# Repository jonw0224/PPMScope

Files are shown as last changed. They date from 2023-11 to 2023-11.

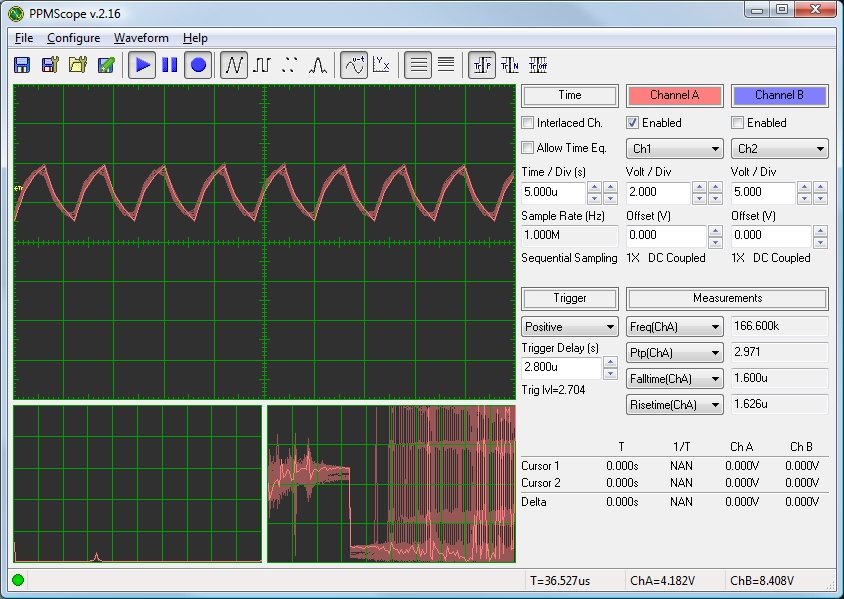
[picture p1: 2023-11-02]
Pictures/DSOScopeDebug20130410.jpg

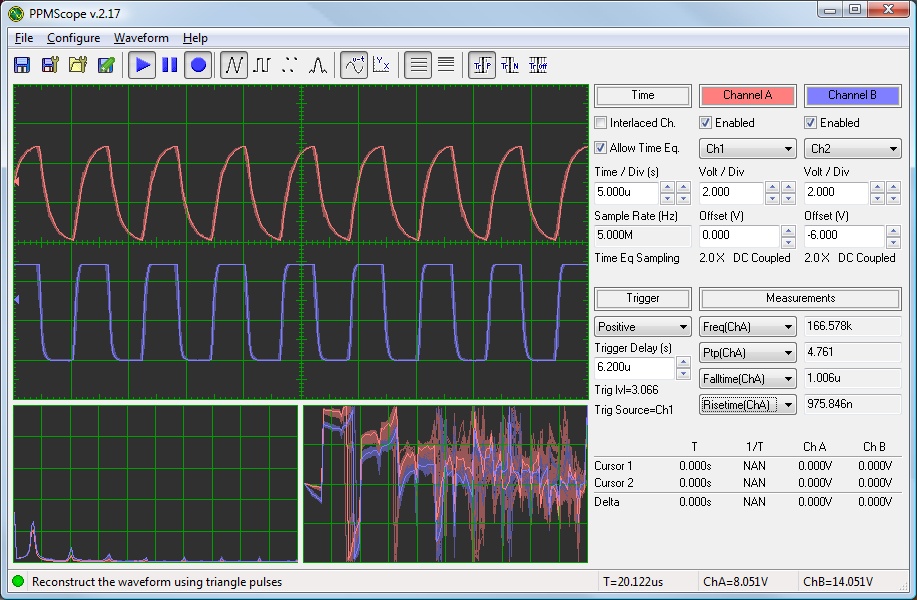
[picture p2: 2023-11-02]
Pictures/PPMScopeDebug20130410.jpg

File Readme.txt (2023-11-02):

PPMScope (PC-PIC-MaximADC Scope)
===============================================================================

Date:  4/17/2014
Author:  Jonathan Weaver, jonw0224@aim.com, http://jonw0224.tripod.com
Version:  2.19 for Windows
Copyright (C) 2014 Jonathan Weaver

PPMScope is a do-it-yourself oscilloscope with an open source design.  The
intent is that the project can be constructed by an electronics hobbiest using
the instructions included.  The design is a compromise between features and
cost.  The bandwidth is lower than a commercial scope, so it's use is limited
to signals of 500 kHz and below.  It's sample buffer is also smaller than
a commercial scope, however sufficient for most oscilloscope functions.

This is a version based on the PIC16F877A microcontroller running with a 20MHz 
clock.  The maximum sampling rate is 1 MHz with a 5 Mhz equivalent sampling
mode.  Currently, the only computer interface supported is the serial port 
and the parallel port.  I have plans to support USB in the future.

Good luck on the construction and I hope you enjoy your oscilloscope.  I am
happy to answer any questions or provide technical support for this design.

See help file, ppmscope.chm, for details on the construction, calibration, 
operation, and software use for the oscilloscope.

Installation of INPOUT to communicate with the parallel port
===============================================================================

This software uses third party software to communicate to the parallel port.  
Inpout is a DLL written originally by Logix4U.net and later adapted for use on
Windows 7 and 64 bit versions of XP and Vista by Phillip Gibbons 
(Phil@highrez.co.uk).  It can be downloaded at 
http://www.highrez.co.uk/downloads/inpout32/

I have included the software in the folder InpOutBinaries_1500

To install the parallel port driver under Windows 7 or Vista, either 

(1) Run PPMScope.exe with administrator privilages the first time it is used, 
    to allow PPMScope to automatically install the driver, or

(2) Run the executable InstallDriver.exe

FOLDER CONTENTS:
===============================================================================

Datasheets -
The manufacturer Datasheets for integrated circuits used.

PCsource -
The source files for the PC, written in C and compiled using dev-cpp v.4.9.9.2
(www.bloodshed.net) or Code::Blocks (www.codeblocks.org).

PICasm -
The PIC assembly source files.

PIChex -
The compiled hex file for the PIC16F877 or PIC16F877A microcontroller.  The 
file was compiled using MPLAB IDE v.8.85 (www.microchip.com).

Schematics -
The schematics for the Oscilloscope in PDF format and TINYCAD 
(tinycad.sourceforge.net) format.

PCB -
The printed circuit board layouts in PDF format and FreePCB 
(www.freepcb.com) format.

Spice - 
LTSpiceIV (http://www.linear.com/designtools/software/#LTspice) model for the
analog portions of the circuit.

REVISION HISTORY:
===============================================================================

Version 2.19 for Windows
-------------------------------------------------------------------------------

See help file for details on the software.

LICENSE AND COPYRIGHT NOTICE FOR SOFTWARE AND FIRMWARE:
===============================================================================

Copyright (C) 2014 Jonathan Weaver

This program is free software: you can redistribute it and/or modify
it under the terms of the GNU General Public License as published by
the Free Software Foundation, either version 3 of the License, or
(at your option) any later version.

This program is distributed in the hope that it will be useful,
but WITHOUT ANY WARRANTY; without even the implied warranty of
MERCHANTABILITY or FITNESS FOR A PARTICULAR PURPOSE.  See the
GNU General Public License for more details.

You should have received a copy of the GNU General Public License
along with this program.  If not, see <http://www.gnu.org/licenses/>.

HARDWARE DESIGN LICENSE:
===============================================================================

Copyright (C) 2014 Jonathan Weaver

The hardware design is licensed under the (cc) Creative Commons 
Attribution-ShareAlike 3.0 Unported (CC BY-SA 3.0) license.  

You are free:

 to Share — to copy, distribute and transmit the work 
 
 to Remix — to adapt the work 

 to make commercial use of the work 

Under the following conditions:

 Attribution — You must attribute the work in the manner specified by the 
   author or licensor (but not in any way that suggests that they endorse 
   you or your use of the work). 

 Share Alike — If you alter, transform, or build upon this work, you may 
   distribute the resulting work only under the same or similar license to this
   one. 

With the understanding that: 

 Waiver— Any of the above conditions can be waived if you get permission from 
   the copyright holder. 

 Public Domain— Where the work or any of its elements is in the public domain 
   under applicable law, that status is in no way affected by the license. 

Other Rights— In no way are any of the following rights affected by the 
license:

 * Your fair dealing or fair use rights, or other applicable copyright 
   exceptions and limitations; 

 * The author's moral rights; 

 * Rights other persons may have either in the work itself or in how the work 
   is used, such as publicity or privacy rights. 

See the Creative Commons License for more details (cc-by-sa-30.txt or 
http://creativecommons.org/licenses/by-sa/3.0/).

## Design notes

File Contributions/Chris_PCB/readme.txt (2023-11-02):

PCB Layout for PPMScope 1.20 by Krzysztof Passowicz

This layout is optimized for single sided board etching.

Contents
========

(1) 28PPMScope v1_2.fpc - FreePCB layout (FreePCB can be downloaded at www.freepcb.com)
(2) bottom_copper.pdf - PDF of bottom side of the layout
(3) bottom_copper.png - Image of bottom side of the layout
(4) bottom_copper.grb - Gerber of bottom side of the layout

License
=======

Copyright (c) 2012 Krzysztof Passowicz

Images and files are licensed under the Creative Commons Attribution-ShareAlike 3.0 Unported license.  For the full license terms, see cc-by-sa.txt.

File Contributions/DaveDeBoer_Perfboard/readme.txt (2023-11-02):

Prototyping perfboard layout for PPMScope v.1.05 contributed by Dave de Boer

Contents
========

(1) scope_v1.05.rst - Lochmaster design file (Lochmaster can be downloaded from www.abacom-online.de).
(2) PPMScope_1.05_top.jpg - Component side layout image
(3) PPMScope_1.05_bot.jpg - Solder side layout image
(4) Build_DavidDeBoer_top.jpg - Component side image of Dave's build
(5) Build_DavidDeBoer_bot.jpg - Solder side image of Dave's build
(6) Build_DavidDeBoer_complete.jpg - Image of the entire scope assembled

License
=======

Copyright (c) 2012 Dave de Boer

Images and files are licensed under the Creative Commons Attribution-ShareAlike 3.0 Unported license.  For the full license terms, see cc-by-sa.txt.

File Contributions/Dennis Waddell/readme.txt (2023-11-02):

PCB Layout and Schematics for Eagle for PPMScope 1.20 by Dennis Waddell.

The files can be used with the free version of Eagle, which can be downloaded at:

http://www.cadsoftusa.com/download-eagle/

License
=======

Copyright (c) 2012 Dennis Waddell

Images and files are licensed under the Creative Commons Attribution-ShareAlike 3.0 Unported license.  For the full license terms, see cc-by-sa.txt.

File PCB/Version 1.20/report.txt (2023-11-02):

FreePCB project report (default units = MIL)
============================================
Project name: PPMScope
Project file: E:\Projects\PPMScope\PCB\Version 1.20\PPMScope v1_2.fpc
Default library folder: c:\program files\freepcb\lib

Drill list
==========
NUMBER  DIAMETER
------  --------
   60   40 MIL
  323   35 MIL
    4   125 MIL

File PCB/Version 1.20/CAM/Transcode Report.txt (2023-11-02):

   ---- Transcoding 'C:\jww\Projects\PPMScope\PCB\Version 1.20\CAM\top_copper.grb' ----   Thu Apr 17 14:20:18 2014

D11   --> D100
D12   --> D101
-----------------------------------------------------------------

   ---- Transcoding 'C:\jww\Projects\PPMScope\PCB\Version 1.20\CAM\top_copper.grb' ----   Thu Apr 17 14:24:19 2014

D18   --> D100
D19   --> D101
D20   --> D102
-----------------------------------------------------------------

   ---- Transcoding 'C:\jww\Projects\PPMScope\PCB\Version 1.20\CAM\top_silk.grb' ----   Thu Apr 17 14:24:19 2014

D11   --> D103
D12   --> D104
-----------------------------------------------------------------

   ---- Transcoding 'C:\jww\Projects\PPMScope\PCB\Version 1.20\CAM\top_copper.grb' ----   Thu Apr 17 14:27:24 2014

D18   --> D100
D19   --> D101
D20   --> D102
-----------------------------------------------------------------

   ---- Transcoding 'C:\jww\Projects\PPMScope\PCB\Version 1.20\CAM\top_silk.grb' ----   Thu Apr 17 14:27:24 2014

D11   --> D103
D12   --> D104
-----------------------------------------------------------------

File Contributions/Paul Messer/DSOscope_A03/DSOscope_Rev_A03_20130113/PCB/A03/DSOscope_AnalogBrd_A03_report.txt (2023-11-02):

FreePCB project report (default units = MIL)
============================================
Project name: DSOscope_AnalogBrd
Project file: C:\Users\pmesser\_Paul\Design\DSOscope\PCB\A03\DSOscope_AnalogBrd_A03.fpc
Default library folder: c:\users\pmesser\_paul\design\my_freepcb_library

Board statistics
==============
Number of copper layers: 4
Number of board outlines: 1
Board outline(s) extent: X = 3700 MIL; Y = 1900 MIL
Number of parts: 81
Number of pins: 246 (88 through-hole, 158 SMT)
Number of vias: 75
Number of holes: 163

Drill list
==========
NUMBER  DIAMETER
------  --------
   75   21 MIL
    3   55 MIL
    2   100 MIL
   63   40 MIL
   16   35 MIL
    4   43 MIL

Part list
=========
For parts on top: the angle is in degrees CCW, as viewed from the top
For parts on the bottom: the angle is in degrees CCW, as viewed from the bottom by flipping the PCB left-right
All centroid coordinates are as viewed from the top

REF          PACKAGE  VALUE        FOOTPRINT  PINS  HOLES    SIDE  ANGLE  CENT X  CENT Y  PIN1 X  PIN1 Y  GLUE W  GLUE X  GLUE Y
---          -------  -----        ---------  ----  -----    ----  -----  ------  ------  ------  ------  ------  ------  ------
 C1             1206                    1206     2      0     top    180   337.5     490     270     490      10   337.5   557.5
C10             0805                    0805     2      0     top     90    1660    1165    1660    1120      10    1615    1165
C11             0805                    0805     2      0     top     90    2620    1025    2620     980      10    2575    1025
C12             0805                    0805     2      0     top    180    2285     800    2240     800      10    2285     845
C13             0805                    0805     2      0     top      0    1295     550    1340     550      10    1295     505
C14             0603                    0603     2      0     top     90    1000  1243.5    1000    1210      10   966.5  1243.5
C15             0603                    0603     2      0     top     90    2700  1283.5    2700    1250      10  2666.5  1283.5
C16             0805                    0805     2      0  bottom    270     940     745     940     790      10     895     745
C17             0805                    0805     2      0     top      0    1155     360    1200     360      10    1155     315
C18             0805                    0805     2      0  bottom    180    2375     700    2330     700      10    2375     655
 C2             0805                    0805     2      0     top     90     500     535     500     490      10     455     535
 C3             1206                    1206     2      0     top      0  3312.5     550    3380     550      10  3312.5   482.5
 C4             0805                    0805     2      0     top    270    3150     505    3150     550      10    3195     505
 C5             0805                    0805     2      0     top     90     950    1455     950    1410      10     905    1455
 C6             0805                    0805     2      0     top     90    1330    1585    1330    1540      10    1285    1585
 C7             0805                    0805     2      0     top    270    2380    1385    2380    1430      10    2425    1385
 C8             0805                    0805     2      0     top    180    2605     340    2560     340      10    2605     385
 C9             0805                    0805     2      0     top     90    1230    1005    1230     960      10    1185    1005
 D1           SOD323                  SOD323     2      0     top    270     910     685     910     760      25     910     685
D10           SOD123                  SOD123     2      0     top      0  2752.5     420    2840     420      25  2752.5     420
D11       LED175VERT              LED175VERT     2      2     top    180     250    1040     200    1040
 D2           SOD323                  SOD323     2      0     top     90     840     685     840     610      25     840     685
 D3            SOT23                   SOT23     3      0     top      0    1900     318    1940     280      10    1902     318
 D4           SOD123                  SOD123     2      0     top    180   847.5     520     760     520      25   847.5     520
 D5           SOD123                  SOD123     2      0     top    180   847.5     430     760     430      25   847.5     430
 D6           SOD323                  SOD323     2      0     top      0    2745     660    2820     660      25    2745     660
 D7           SOD323                  SOD323     2      0     top    180    2745     590    2670     590      25    2745     590
 D8            SOT23                   SOT23     3      0     top      0    2140     318    2180     280      10    2142     318
 D9           SOD123                  SOD123     2      0     top      0  2752.5     510    2840     510      25  2752.5     510
 J1           TBLKx2                  TBLKx2     2      2  bottom     90     150     550     150     550
 J2           TBLKx2                  TBLKx2     2      2  bottom    270    3550     750    3550     750
 J3  SqPinSocket1x18         SqPinSocket1x18    18     18  bottom    180    1000     150    1000     150
 J4   SqPinSocket1x7          SqPinSocket1x7     7      7  bottom     90    3550    1150    3550    1150
 R1             0805                    0805     2      0     top     90     580     505     580     460      10     535     505
R10             0805                    0805     2      0     top      0     555    1050     600    1050      10     555    1005
R11             0805                    0805     2      0     top      0     915    1580     960    1580      10     915    1535
R12             0805                    0805     2      0     top     90     870    1455     870    1410      10     825    1455
R13            PV36W                   PV36W     3      3     top    270     180    1590     180    1590
R14             0805                    0805     2      0     top    270    3060     505    3060     550      10    3105     505
R15             0805                    0805     2      0     top     90    2970     505    2970     460      10    2925     505
R16             0805                    0805     2      0     top     90    2870     795    2870     750      10    2825     795
R17             0805                    0805     2      0     top      0    1485    1580    1530    1580      10    1485    1535
R18             0805                    0805     2      0     top     90    2770    1255    2770    1210      10    2725    1255
R19             0805                    0805     2      0     top    270    2790     795    2790     840      10    2835     795
 R2             0805                    0805     2      0     top     90     360     655     360     610      10     315     655
R20             0805                    0805     2      0     top      0    2475    1580    2520    1580      10    2475    1535
R21             0805                    0805     2      0     top     90    2850    1255    2850    1210      10    2805    1255
R22             0805                    0805     2      0     top      0    1875    1100    1920    1100      10    1875    1055
R23             0805                    0805     2      0     top    180    3145    1050    3100    1050      10    3145    1095
R24             0805                    0805     2      0     top    180    2785    1580    2740    1580      10    2785    1625
R25             0805                    0805     2      0     top     90    2830    1445    2830    1400      10    2785    1445
R26             0805                    0805     2      0     top    270    2570     585    2570     630      10    2615     585
R27             0805                    0805     2      0     top    180    2335     340    2290     340      10    2335     385
R28             0805                    0805     2      0     top    270    2430     855    2430     900      10    2475     855
R29         POTVERT1                POTVERT1     5      5     top    180    1850     700    1460     550
 R3             0805                    0805     2      0     top     90     360     825     360     780      10     315     825
R30             0805                    0805     2      0     top    180     195    1220     150    1220      10     195    1265
R31            PV36W                   PV36W     3      3     top    270    3400    1590    3400    1590
R32             0805                    0805     2      0     top     90    1650    1615    1650    1570      10    1605    1615
R33             0805                    0805     2      0     top     90     280     825     280     780      10     235     825
R34             0805                    0805     2      0  bottom     90    2830     745    2830     700      10    2875     745
R35             0805                    0805     2      0  bottom     90     690     535     690     490      10     735     535
R36             0805                    0805     2      0  bottom    270    3320     745    3320     790      10    3275     745
R37             0805                    0805     2      0     top    270    2070    1445    2070    1490      10    2115    1445
 R4             0805                    0805     2      0     top    270    1330    1255    1330    1300      10    1375    1255
 R5             0805                    0805     2      0     top     90     930    1255     930    1210      10     885    1255
 R6             0805                    0805     2      0     top     90     400     995     400     950      10     355     995
 R7             0805                    0805     2      0     top    180    1175    1580    1130    1580      10    1175    1625
 R8             0805                    0805     2      0     top     90     850    1255     850    1210      10     805    1255
 R9             0805                    0805     2      0     top     90    1330    1075    1330    1030      10    1285    1075
SW1       SWDP3TSLD2              SWDP3TSLD2     8      8     top    180     250     250     250     250
SW2     SWDPDTTOGSM1            SWDPDTTOGSM1     6      6     top     90     605     800     690     700
SW3     SWDPDTTOGSM1            SWDPDTTOGSM1     6      6     top     90     605    1400     690    1300
SW4     SWDPDTTOGSM1            SWDPDTTOGSM1     6      6     top      0    1850    1405    1950    1490
SW5       SWDP3TSLD2              SWDP3TSLD2     8      8     top    180    3050     250    3050     250
SW6     SWDPDTTOGSM1            SWDPDTTOGSM1     6      6     top     90    3095     800    3180     700
SW7     SWDPDTTOGSM1            SWDPDTTOGSM1     6      6     top     90    3095    1400    3180    1300
 U1            SOIC8                   SOIC8     8      0     top    180    1155    1320    1080    1210      10    1155    1285
 U2            SOIC8                   SOIC8     8      0     top    180    2545    1320    2470    1210      10    2545    1285
 U3            SOIC8                   SOIC8     8      0     top    180    1505    1320    1430    1210      10    1505    1285
 U4            SOIC8                   SOIC8     8      0     top      0    2405     580    2480     690      10    2405     615

Gerber file settings
====================
Include board outline: YES
Include moires: NO
Include layer description text: NO
Include pilot holes: YES
Connect SMT pins to copper areas: YES
Use thermals for SMT pins: YES
Use thermals for through-hole pins: YES
Use thermals for vias: YES
Make solder-mask cutouts for vias: NO
Use 90-degree thermals for round pins: NO
Copper to copper-fill clearance: 15 MIL
Hole-edge to copper-fill clearance: 15 MIL
Solder mask clearance: 8 MIL
Pilot hole diameter: 10 MIL
Minimum silkscreen line width: 7 MIL
Thermal relief line width: 25 MIL
Board outline line width: 10 MIL
Minimum annular ring width (pins): 7 MIL
Minimum annular ring width (vias): 5 MIL
Amount to shrink SMT pads for paste mask: 0 MIL

DRC settings
============
Minimum trace width: 10 MIL
Minimum pad to pad clearance: 10 MIL
Minimum pad to trace clearance: 10 MIL
Minimum trace to trace clearance: 10 MIL
Minimum hole to copper clearance: 15 MIL
Minimum hole to hole clearance: 25 MIL
Minimum annular ring (pins): 7 MIL
Minimum annular ring (vias): 5 MIL
Minimum board edge to copper clearance: 25 MIL
Minimum board edge to hole clearance: 25 MIL
Minimum copper area to copper area clearance: 10 MIL

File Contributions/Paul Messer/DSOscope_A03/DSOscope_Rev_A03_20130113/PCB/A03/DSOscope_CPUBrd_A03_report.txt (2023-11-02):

FreePCB project report (default units = MIL)
============================================
Project name: DSOscope_CPUBrd
Project file: C:\Users\pmesser\_Paul\Design\DSOscope\PCB\A03\DSOscope_CPUBrd_A03.fpc
Default library folder: c:\users\pmesser\_paul\design\my_freepcb_library

Board statistics
==============
Number of copper layers: 4
Number of board outlines: 3
Board outline(s) extent: X = 3700 MIL; Y = 1900 MIL
Number of parts: 91 (without footprints = 14)
Number of pins: 264 (57 through-hole, 207 SMT)
Number of vias: 96
Number of holes: 153

Drill list
==========
NUMBER  DIAMETER
------  --------
   96   21 MIL
   10   35 MIL
    2   90 MIL
   37   41 MIL
    4   36 MIL
    4   52 MIL

Part list
=========
For parts on top: the angle is in degrees CCW, as viewed from the top
For parts on the bottom: the angle is in degrees CCW, as viewed from the bottom by flipping the PCB left-right
All centroid coordinates are as viewed from the top

   REF    PACKAGE  VALUE  FOOTPRINT  PINS  HOLES    SIDE  ANGLE  CENT X  CENT Y  PIN1 X  PIN1 Y  GLUE W  GLUE X  GLUE Y
   ---    -------  -----  ---------  ----  -----    ----  -----  ------  ------  ------  ------  ------  ------  ------
 BOM_1  NOPACKAGE                                                                              
BOM_10  NOPACKAGE                                                                              
BOM_11  NOPACKAGE                                                                              
BOM_12  NOPACKAGE                                                                              
BOM_13  NOPACKAGE                                                                              
BOM_14  NOPACKAGE                                                                              
 BOM_2  NOPACKAGE                                                                              
 BOM_3  NOPACKAGE                                                                              
 BOM_4  NOPACKAGE                                                                              
 BOM_5  NOPACKAGE                                                                              
 BOM_6  NOPACKAGE                                                                              
 BOM_7  NOPACKAGE                                                                              
 BOM_8  NOPACKAGE                                                                              
 BOM_9  NOPACKAGE                                                                              
    C1       0805              0805     2      0  bottom    180    1405     750    1360     750      10    1405     705
   C10     RAD248            RAD248     2      2     top      0    2420     400    2470     400
   C11       0805              0805     2      0  bottom      0    2955    1590    3000    1590      10    2955    1635
   C12     RAD248            RAD248     2      2     top     90    2790    1750    2790    1700
   C13     RAD394            RAD394     2      2     top    270    3500    1110    3500    1210
   C14       0805              0805     2      0  bottom    270    3400    1105    3400    1150      10    3355    1105
   C15       0805              0805     2      0     top     90    2710     555    2710     510      10    2665     555
   C16     RAD248            RAD248     2      2     top     90    2710    1220    2710    1170
   C17       0805              0805     2      0     top     90    3230    1265    3230    1220      10    3185    1265
   C18     RAD394            RAD394     2      2     top     90    3500     700    3500     600
   C19       0805              0805     2      0  bottom     90    3400     915    3400     870      10    3445     915
    C2       0805              0805     2      0  bottom     90     770     915     770     870      10     815     915
   C20       0805              0805     2      0  bottom    270    3000     785    3000     830      10    2955     785
   C21       0603              0603     2      0  bottom     90    2200   773.5    2200     740      10  2233.5   773.5
   C22       0805              0805     2      0  bottom     90    1870     875    1870     830      10    1915     875
   C23       0603              0603     2      0  bottom      0  1796.5     660    1830     660      10  1796.5   693.5
   C24       0805              0805     2      0     top     90    2610     355    2610     310      10    2565     355
   C25       0805              0805     2      0  bottom    180    2815     660    2770     660      10    2815     615
    C3       0603              0603     2      0     top      0   506.5     840     540     840      10   506.5   806.5
    C4       0603              0603     2      0     top    180   313.5     840     280     840      10   313.5   873.5
    C5       0805              0805     2      0  bottom    270     980     955     980    1000      10     935     955
    C6       0805              0805     2      0  bottom     90     770    1085     770    1040      10     815    1085
    C7       0805              0805     2      0     top    180     615    1560     570    1560      10     615    1605
    C8     RAD248            RAD248     2      2     top     90    2490    1080    2490    1030
    C9       0805              0805     2      0     top     90    2710     745    2710     700      10    2665     745
    D1    DO35SMT           DO35SMT     2      0     top    180     390    1670     290    1670      10     390    1770
    D2     SOD123            SOD123     2      0     top    180   677.5    1670     590    1670      25   677.5    1670
    D4       DO41              DO41     2      2     top     90    3600    1550    3600    1300
    D5       DO41              DO41     2      2     top     90    3250     850    3250     600
    F1    miniSMD           miniSMD     2      0     top    180    2210    1130    2110    1130      10    2210    1230
    J1  CutStrap1         CutStrap1     3      2     top     90     300     980     300     980
    J2   SqPin1x7          SqPin1x7     7      7     top     90     150    1150     150    1150
    J3  SqPin1x18         SqPin1x18    18     18  bottom      0    2700     150    2700     150
    J4   SqPin1x6          SqPin1x6     6      6     top     90    1390    1290    1390    1290
    J5      USBB1             USBB1     6      6     top      0    1850    1685    1801    1410
    L1    INDUCT1           INDUCT1     2      0     top    180    3340    1670    3340    1550      25    3340    1670
    L2    INDUCT1           INDUCT1     2      0     top     90    2980     750    3100     750      25    2980     750
    L3       1210              1210     2      0     top    270    2720   352.5    2720     420      10  2787.5   352.5
    L4       1210              1210     2      0  bottom    270    2830   822.5    2830     890      10  2762.5   822.5
    R1       0805              0805     2      0     top     90     520    1205     520    1160      10     475    1205
   R10       0805              0805     2      0     top    180     785    1560     740    1560      10     785    1605
   R11       0805              0805     2      0     top    180     445    1560     400    1560      10     445    1605
   R12       0805              0805     2      0  bottom    270     520    1205     520    1250      10     475    1205
   R13       0805              0805     2      0     top    180     445    1480     400    1480      10     445    1525
   R14       0805              0805     2      0     top      0     685    1350     730    1350      10     685    1305
   R15       0805              0805     2      0     top     90    1860     545    1860     500      10    1815     545
   R16       0805              0805     2      0     top     90    2000     545    2000     500      10    1955     545
   R17       0805              0805     2      0     top    180    1215    1690    1170    1690      10    1215    1735
   R18       0805              0805     2      0     top    180    1215    1790    1170    1790      10    1215    1835
    R2       0805              0805     2      0     top    270    1000     365    1000     410      10    1045     365
   R21       0805              0805     2      0     top    270    2920    1435    2920    1480      10    2965    1435
   R22       0805              0805     2      0     top    270    3000    1435    3000    1480      10    3045    1435
   R23       0805              0805     2      0     top     90    3100    1435    3100    1390      10    3055    1435
   R24       0805              0805     2      0     top    270    2760    1535    2760    1580      10    2805    1535
   R25       0805              0805     2      0     top    270    2840    1535    2840    1580      10    2885    1535
   R26       0805              0805     2      0     top      0    2795    1410    2840    1410      10    2795    1365
   R27       0805              0805     2      0     top    180    2715    1040    2670    1040      10    2715    1085
   R28       0805              0805     2      0     top    180    2715     960    2670     960      10    2715    1005
   R29       0805              0805     2      0     top      0    2925    1310    2970    1310      10    2925    1265
    R3       0805              0805     2      0     top      0     725     720     770     720      10     725     675
   R30       0805              0805     2      0     top    180    2925    1220    2880    1220      10    2925    1265
   R31       0805              0805     2      0     top    180    3095    1310    3050    1310      10    3095    1355
   R32       0805              0805     2      0     top     90    1760    1155    1760    1110      10    1715    1155
   R33       0805              0805     2      0  bottom     90     850    1315     850    1270      10     895    1315
   R34       0805              0805     2      0  bottom     90     930    1315     930    1270      10     975    1315
   R35       0805              0805     2      0     top      0     685    1430     730    1430      10     685    1385
    R4       0805              0805     2      0     top      0    2245     810    2290     810      10    2245     765
    R5       0805              0805     2      0     top      0    1205    1550    1250    1550      10    1205    1505
    R6       0805              0805     2      0     top    180    1635    1200    1590    1200      10    1635    1245
    R7       0805              0805     2      0     top      0    1675    1280    1720    1280      10    1675    1235
    R8       0805              0805     2      0     top    270     910    1605     910    1650      10     955    1605
    R9       0805              0805     2      0     top    270     990    1605     990    1650      10    1035    1605
    U1     SSOP28            SSOP28    28      0     top    180    1489   577.5    1320     410      25    1489   577.5
    U2     TQFP44            TQFP44    44      0     top     90  1002.5  1037.5  1272.5     880      10  1002.5  1037.5
    U4      SOIC8             SOIC8     8      0     top      0    3025    1690    3100    1800      10    3025    1725
    U5      SOIC8             SOIC8     8      0     top     90    3000    1055    3110     980      10    3035    1055
    X1   HC49VERT          HC49VERT     2      2     top     90     375     680     470     680

Gerber file settings
====================
Include board outline: YES
Include moires: NO
Include layer description text: NO
Include pilot holes: YES
Connect SMT pins to copper areas: NO
Use thermals for SMT pins: YES
Use thermals for through-hole pins: YES
Use thermals for vias: YES
Make solder-mask cutouts for vias: NO
Use 90-degree thermals for round pins: NO
Copper to copper-fill clearance: 15 MIL
Hole-edge to copper-fill clearance: 15 MIL
Solder mask clearance: 8 MIL
Pilot hole diameter: 10 MIL
Minimum silkscreen line width: 5 MIL
Thermal relief line width: 20 MIL
Board outline line width: 5 MIL
Minimum annular ring width (pins): 7 MIL
Minimum annular ring width (vias): 5 MIL
Amount to shrink SMT pads for paste mask: 0 MIL

DRC settings
============
Minimum trace width: 10 MIL
Minimum pad to pad clearance: 10 MIL
Minimum pad to trace clearance: 10 MIL
Minimum trace to trace clearance: 10 MIL
Minimum hole to copper clearance: 15 MIL
Minimum hole to hole clearance: 25 MIL
Minimum annular ring (pins): 7 MIL
Minimum annular ring (vias): 5 MIL
Minimum board edge to copper clearance: 25 MIL
Minimum board edge to hole clearance: 25 MIL
Minimum copper area to copper area clearance: 10 MIL

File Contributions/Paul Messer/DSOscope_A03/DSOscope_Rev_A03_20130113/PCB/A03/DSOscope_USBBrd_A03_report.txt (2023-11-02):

FreePCB project report (default units = MIL)
============================================
Project name: DSOscope_USBBrd_A03
Project file: C:\Users\pmesser\_Paul\Design\DSOscope\PCB\A03\DSOscope_USBBrd_A03.fpc
Default library folder: c:\users\pmesser\_paul\design\my_freepcb_library

Board statistics
==============
Number of copper layers: 4
Number of board outlines: 1
Board outline(s) extent: X = 1150 MIL; Y = 925 MIL
Number of parts: 18
Number of pins: 66 (6 through-hole, 60 SMT)
Number of vias: 19
Number of holes: 25

Drill list
==========
NUMBER  DIAMETER
------  --------
   19   21 MIL
    6   41 MIL

Part list
=========
For parts on top: the angle is in degrees CCW, as viewed from the top
For parts on the bottom: the angle is in degrees CCW, as viewed from the bottom by flipping the PCB left-right
All centroid coordinates are as viewed from the top

REF         PACKAGE  VALUE       FOOTPRINT  PINS  HOLES    SIDE  ANGLE  CENT X  CENT Y  PIN1 X  PIN1 Y  GLUE W  GLUE X  GLUE Y
---         -------  -----       ---------  ----  -----    ----  -----  ------  ------  ------  ------  ------  ------  ------
 C1            0805                   0805     2      0     top    180     815     535     770     535      10     815     580
 C2            0805                   0805     2      0     top    270      80     420      80     465      10     125     420
 C3            0805                   0805     2      0  bottom      0     385     575     430     575      10     385     620
 D1       1206DIODE              1206DIODE     2      0     top      0   182.5     825     250     825      10   182.5   757.5
 D2       1206DIODE              1206DIODE     2      0     top    180   457.5     825     390     825      10   457.5   892.5
 L1            0805                   0805     2      0     top    180     815     455     770     455      10     815     500
 P1  SqPinSocket1x6         SqPinSocket1x6     6      6  bottom     90    1000     325    1000     325
 R1            0805                   0805     2      0     top     90     100     650     100     605      10      55     650
R10            0805                   0805     2      0  bottom      0     165      85     210      85      10     165     130
 R2            0805                   0805     2      0     top      0     705     825     750     825      10     705     780
 R3            0805                   0805     2      0     top      0     735     245     780     245      10     735     200
 R4            0805                   0805     2      0     top      0     735     165     780     165      10     735     120
 R5            0805                   0805     2      0     top      0     555      85     600      85      10     555      40
 R6            0805                   0805     2      0     top    180     175      85     130      85      10     175     130
 R7            0805                   0805     2      0  bottom    180     745     245     700     245      10     745     200
 R8            0805                   0805     2      0  bottom    180     745     165     700     165      10     745     120
 R9            0805                   0805     2      0  bottom    180     565      85     520      85      10     565      40
 U1          SSOP28                 SSOP28    28      0     top    180     369   422.5     200     255      25     369   422.5

Gerber file settings
====================
Include board outline: YES
Include moires: NO
Include layer description text: NO
Include pilot holes: YES
Connect SMT pins to copper areas: NO
Use thermals for SMT pins: YES
Use thermals for through-hole pins: YES
Use thermals for vias: YES
Make solder-mask cutouts for vias: NO
Use 90-degree thermals for round pins: NO
Copper to copper-fill clearance: 15 MIL
Hole-edge to copper-fill clearance: 15 MIL
Solder mask clearance: 8 MIL
Pilot hole diameter: 10 MIL
Minimum silkscreen line width: 5 MIL
Thermal relief line width: 20 MIL
Board outline line width: 5 MIL
Minimum annular ring width (pins): 7 MIL
Minimum annular ring width (vias): 5 MIL
Amount to shrink SMT pads for paste mask: 0 MIL

DRC settings
============
Minimum trace width: 10 MIL
Minimum pad to pad clearance: 10 MIL
Minimum pad to trace clearance: 10 MIL
Minimum trace to trace clearance: 10 MIL
Minimum hole to copper clearance: 15 MIL
Minimum hole to hole clearance: 25 MIL
Minimum annular ring (pins): 7 MIL
Minimum annular ring (vias): 5 MIL
Minimum board edge to copper clearance: 25 MIL
Minimum board edge to hole clearance: 25 MIL
Minimum copper area to copper area clearance: 10 MIL

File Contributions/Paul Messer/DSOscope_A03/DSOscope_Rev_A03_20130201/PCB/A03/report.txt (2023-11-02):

FreePCB project report (default units = MIL)
============================================
Project name: DSOscope_AnalogBrd
Project file: C:\Google Drive\Projects\PPMScope\Contributions\Paul Messer\DSOscope_A03\DSOscope_Rev_A03_20130201\PCB\A03\DSOscope_AnalogBrd_A03.fpc
Default library folder: c:\users\pmesser\_paul\design\my_freepcb_library

Drill list
==========
NUMBER  DIAMETER
------  --------
   20   21 MIL
    3   55 MIL
    2   100 MIL
   63   40 MIL
    2   14 MIL
   16   35 MIL
    4   43 MIL
   52   30 MIL

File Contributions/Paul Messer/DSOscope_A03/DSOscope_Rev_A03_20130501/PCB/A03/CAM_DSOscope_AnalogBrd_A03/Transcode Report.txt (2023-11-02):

   ---- Transcoding 'C:\jww\Projects\PPMScope\Contributions\Paul Messer\DSOscope_A03\DSOscope_Rev_A03_20130501\PCB\A03\CAM_DSOscope_AnalogBrd_A03\bottom_silk.grb' ----   Fri Aug 15 15:07:52 2014

D11   --> D100
-----------------------------------------------------------------

   ---- Transcoding 'C:\jww\Projects\PPMScope\Contributions\Paul Messer\DSOscope_A03\DSOscope_Rev_A03_20130501\PCB\A03\CAM_DSOscope_AnalogBrd_A03\inner_copper_1.grb' ----   Fri Aug 15 15:07:52 2014

D11   --> D101
D12   --> D102
D14   --> D103
D15   --> D104
-----------------------------------------------------------------

   ---- Transcoding 'C:\jww\Projects\PPMScope\Contributions\Paul Messer\DSOscope_A03\DSOscope_Rev_A03_20130501\PCB\A03\CAM_DSOscope_AnalogBrd_A03\inner_copper_2.grb' ----   Fri Aug 15 15:07:52 2014

D11   --> D105
D12   --> D106
D13   --> D107
D14   --> D108
-----------------------------------------------------------------

   ---- Transcoding 'C:\jww\Projects\PPMScope\Contributions\Paul Messer\DSOscope_A03\DSOscope_Rev_A03_20130501\PCB\A03\CAM_DSOscope_AnalogBrd_A03\top_silk.grb' ----   Fri Aug 15 15:18:05 2014

D11   --> D100
-----------------------------------------------------------------

   ---- Transcoding 'C:\jww\Projects\PPMScope\Contributions\Paul Messer\DSOscope_A03\DSOscope_Rev_A03_20130501\PCB\A03\CAM_DSOscope_AnalogBrd_A03\top_silk.grb' ----   Fri Aug 15 15:23:48 2014

D11   --> D100
-----------------------------------------------------------------

   ---- Transcoding 'C:\jww\Projects\PPMScope\Contributions\Paul Messer\DSOscope_A03\DSOscope_Rev_A03_20130501\PCB\A03\CAM_DSOscope_AnalogBrd_A03\bottom_silk.grb' ----   Mon Aug 18 08:13:33 2014

D11   --> D100
-----------------------------------------------------------------

   ---- Transcoding 'C:\jww\Projects\PPMScope\Contributions\Paul Messer\DSOscope_A03\DSOscope_Rev_A03_20130501\PCB\A03\CAM_DSOscope_AnalogBrd_A03\inner_copper_1.grb' ----   Mon Aug 18 08:13:33 2014

D11   --> D101
D12   --> D102
D14   --> D103
D15   --> D104
-----------------------------------------------------------------

   ---- Transcoding 'C:\jww\Projects\PPMScope\Contributions\Paul Messer\DSOscope_A03\DSOscope_Rev_A03_20130501\PCB\A03\CAM_DSOscope_AnalogBrd_A03\inner_copper_2.grb' ----   Mon Aug 18 08:13:33 2014

D11   --> D105
D12   --> D106
D13   --> D107
D14   --> D108
-----------------------------------------------------------------

   ---- Transcoding 'C:\jww\Projects\PPMScope\Contributions\Paul Messer\DSOscope_A03\DSOscope_Rev_A03_20130501\PCB\A03\CAM_DSOscope_AnalogBrd_A03\top_copper.grb' ----   Mon Aug 18 08:13:33 2014

D11   --> D109
D12   --> D110
D13   --> D111
D14   --> D112
D15   --> D113
D16   --> D114
D17   --> D115
D18   --> D116
D19   --> D117
D20   --> D118
D21   --> D119
D22   --> D120
D23   --> D121
D24   --> D122
D25   --> D123
D26   --> D124
D27   --> D125
D28   --> D126
D29   --> D127
D31   --> D128
D32   --> D129
D33   --> D130
D34   --> D131
D35   --> D132
D36   --> D133
-----------------------------------------------------------------

   ---- Transcoding 'C:\jww\Projects\PPMScope\Contributions\Paul Messer\DSOscope_A03\DSOscope_Rev_A03_20130501\PCB\A03\CAM_DSOscope_AnalogBrd_A03\top_silk.grb' ----   Mon Aug 18 08:13:33 2014

D11   --> D134
-----------------------------------------------------------------

   ---- Transcoding 'C:\jww\Projects\PPMScope\Contributions\Paul Messer\DSOscope_A03\DSOscope_Rev_A03_20130501\PCB\A03\CAM_DSOscope_AnalogBrd_A03\bottom_silk.grb' ----   Mon Aug 18 08:17:52 2014

D11   --> D100
-----------------------------------------------------------------

   ---- Transcoding 'C:\jww\Projects\PPMScope\Contributions\Paul Messer\DSOscope_A03\DSOscope_Rev_A03_20130501\PCB\A03\CAM_DSOscope_AnalogBrd_A03\inner_copper_1.grb' ----   Mon Aug 18 08:17:52 2014

D11   --> D101
D12   --> D102
D14   --> D103
D15   --> D104
-----------------------------------------------------------------

   ---- Transcoding 'C:\jww\Projects\PPMScope\Contributions\Paul Messer\DSOscope_A03\DSOscope_Rev_A03_20130501\PCB\A03\CAM_DSOscope_AnalogBrd_A03\inner_copper_2.grb' ----   Mon Aug 18 08:17:52 2014

D11   --> D105
D12   --> D106
D13   --> D107
D14   --> D108
-----------------------------------------------------------------

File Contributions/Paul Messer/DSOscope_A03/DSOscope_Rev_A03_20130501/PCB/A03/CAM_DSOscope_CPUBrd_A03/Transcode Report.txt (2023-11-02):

   ---- Transcoding 'C:\jww\Projects\PPMScope\Contributions\Paul Messer\DSOscope_A03\DSOscope_Rev_A03_20130501\PCB\A03\CAM_DSOscope_CPUBrd_A03\bottom_silk.grb' ----   Fri Aug 15 15:20:28 2014

D11   --> D100
D12   --> D101
-----------------------------------------------------------------

   ---- Transcoding 'C:\jww\Projects\PPMScope\Contributions\Paul Messer\DSOscope_A03\DSOscope_Rev_A03_20130501\PCB\A03\CAM_DSOscope_CPUBrd_A03\inner_copper_1.grb' ----   Fri Aug 15 15:20:28 2014

D11   --> D102
D12   --> D103
D13   --> D104
D14   --> D105
D15   --> D106
-----------------------------------------------------------------

   ---- Transcoding 'C:\jww\Projects\PPMScope\Contributions\Paul Messer\DSOscope_A03\DSOscope_Rev_A03_20130501\PCB\A03\CAM_DSOscope_CPUBrd_A03\inner_copper_2.grb' ----   Fri Aug 15 15:20:28 2014

D11   --> D107
D12   --> D108
D13   --> D109
D14   --> D110
D15   --> D111
D16   --> D112
D17   --> D113
D18   --> D114
D19   --> D115
D20   --> D116
D21   --> D117
-----------------------------------------------------------------

   ---- Transcoding 'C:\jww\Projects\PPMScope\Contributions\Paul Messer\DSOscope_A03\DSOscope_Rev_A03_20130501\PCB\A03\CAM_DSOscope_CPUBrd_A03\top_silk.grb' ----   Fri Aug 15 15:22:16 2014

D11   --> D100
D12   --> D101
-----------------------------------------------------------------

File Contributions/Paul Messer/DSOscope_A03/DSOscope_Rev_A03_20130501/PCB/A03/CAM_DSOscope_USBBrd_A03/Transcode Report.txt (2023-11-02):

   ---- Transcoding 'C:\jww\Projects\PPMScope\Contributions\Paul Messer\DSOscope_A03\DSOscope_Rev_A03_20130501\PCB\A03\CAM_DSOscope_USBBrd_A03\bottom_silk.grb' ----   Fri Aug 15 15:25:17 2014

D11   --> D100
-----------------------------------------------------------------

   ---- Transcoding 'C:\jww\Projects\PPMScope\Contributions\Paul Messer\DSOscope_A03\DSOscope_Rev_A03_20130501\PCB\A03\CAM_DSOscope_USBBrd_A03\top_silk.grb' ----   Fri Aug 15 15:26:36 2014

D11   --> D100
-----------------------------------------------------------------

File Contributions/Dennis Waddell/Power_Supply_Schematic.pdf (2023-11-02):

Power Supply Schematic

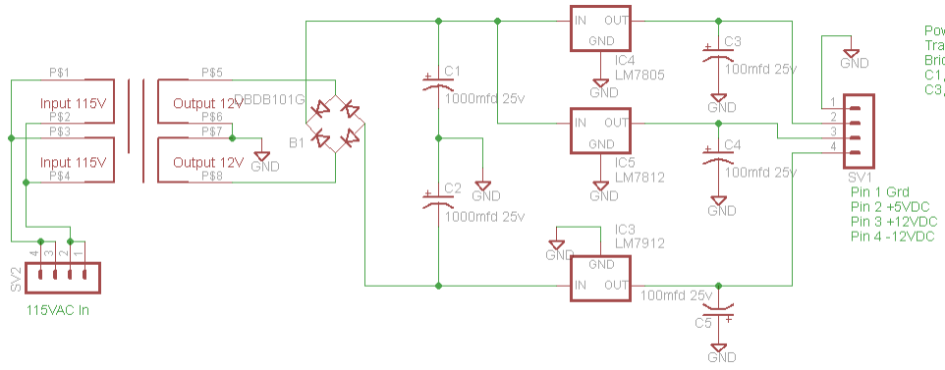
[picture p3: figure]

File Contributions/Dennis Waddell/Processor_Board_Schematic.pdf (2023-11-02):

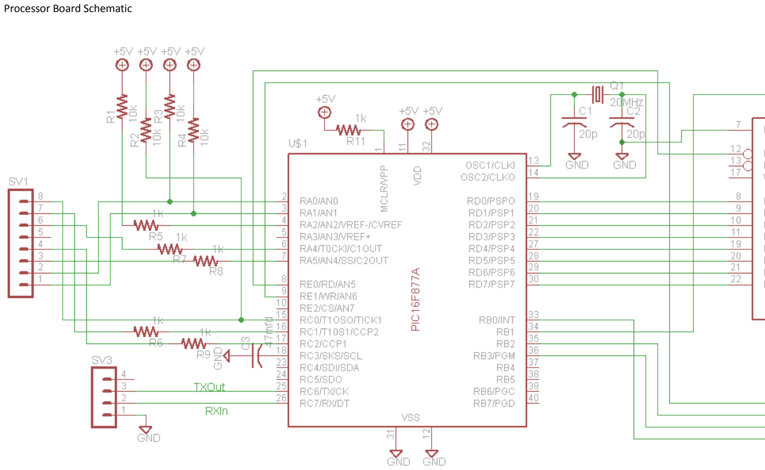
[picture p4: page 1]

Processor Board Schematic

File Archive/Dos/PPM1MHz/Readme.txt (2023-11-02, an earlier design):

PPMScope (PC-PIC-MaximADC Scope)
===============================================================================

Date:  1/23/2006
Author:  Jonathan Weaver, jonw0224@netscape.net, http:\\jonw0224.tripod.com
Version:  0.101 Alpha for DOS
Copyright (C) 2006 Jonathan Weaver

PIC16F877A version with 20MHz clock (1 MHz maximum sample rate) to
interface with the parallel port (LPT1).

This version of PPMScope is an incomplete version.  It is not meant to be a
final product, but only to illustrate some of the principle of building a
PC platform oscilloscope.  The circuit schematic is fairly stable at this
point.

There is a more final version of PPMScope currently being developed.  It will
support repetitive waveform sampling up to 5 MHz and be able to sample 
repetitive waveforms up to 2 MHz.

I do not anticipate the circuit schematic will change much in the next
generation, however, I have MUCH work to do developing the software and 
firmware.

In the end, I want to have a DOS version of the software and a Java 
cross-platform version.  The reason for a DOS version is simplicity and speed.
The DOS version can be used on a slower PC without major performance hits.
I have not begun development of the Java software.

FOLDER CONTENTS:
===============================================================================

Datasheets -
The manufacturer Datasheets for integrated circuits used.

PCbin -
The compiled computer program to interface with the PPMScope.  The program
was compiled with PowerBASIC v.3.2 Compiler for DOS (www.powerbasic.com).
The program is a graphics based DOS interface.  Oscillo.exe is the compiled
program which tries to establish communication with the PPMScope hardware
connect to LPT1.  OscDemo.exe is the compiled program which simulates the 
hardware and is simply a demo.

PCsource -
The PowerBASIC source files.

PICasm -
The PIC assembly source files.

PIChex -
The compiled hex file for the PIC16F877A microcontroller.  The file was
compiled using MPLAB IDE v.6.2 (www.microchip.com).

Schematics -
The schematics for the Oscilloscope in PDF format and TINYCAD format.

REVISION HISTORY:
===============================================================================

Version 0.102 alpha for DOS - Released
-------------------------------------------------------------------------------

New Features:

Implementation of interrupt based trigger to reduce the trigger jitter.  New 
feature added on 3/28/2006.

Lengthening of the channel buffer from 64 samples to 256 samples for all sample
modes.  New feature added on 3/28/2006 thru 4/12/2006.

Bug fixes:

A correction to the schematic.  RE1 on the PIC was shown wired to RB1 instead
of RB2, which is correct.  4/12/2006.

Version 0.101 alpha for DOS - Released January 23, 2006
-------------------------------------------------------------------------------

A correction to the schematic.

Version 0.1 alpha for DOS - Released January 14, 2006
-------------------------------------------------------------------------------

Initial release.  Generally, the code was changed to work with a PIC16F877A and 
sample at 1 Mhz.

LICENSE AND COPYRIGHT NOTICE FOR SOFTWARE:
===============================================================================

Copyright (C) 2006 Jonathan Weaver

This program is free software; you can redistribute it and/or modify it
under the terms of the GNU General Public License as published by the Free
Software Foundation; either version 2 of the License, or (at your option)
any later version.

This program is distributed in the hope that it will be useful, but WITHOUT
ANY WARRANTY; without even the implied warranty of MERCHANTABILITY or
FITNESS FOR A PARTICULAR PURPOSE.  See the GNU General Public License for
more details (gpl.txt).

You should have received a copy of the GNU General Public License along
with this program; if not, write to the Free Software Foundation, Inc.,
51 Franklin St, Fifth Floor, Boston, MA  02110-1301  USA

HARDWARE DESIGN TERMS AND CONDITIONS:
===============================================================================

Hardware designs (including schematics, instructions, and techniques) are
presented in hopes that they will be useful and under the following
conditions:

By downloading or using the hardware design, you accept the conditions
below. If you do not agree, you should not download or use the hardware
design.

You are given permission to use the hardware design without royalty.

You may redistribute the hardware designs provided that you keep the author
and copyright information intact and that you distribute the hardware
design with an unmodified copy of these terms and conditions.

You may modify the hardware designs, but a prominent notice including the
author, the date, and a brief description of the modification should
accompany any modification. You may not remove references to these terms
and conditions or any copyright notices.

If you distribute a device created using the hardware design, you must
distribute the hardware design under these terms and conditions.

The copyright holders are under no obligation to provide maintenance,
updates, or technical support for the hardware design.

BECAUSE THE HARDWARE DESIGN IS LICENSED FREE OF CHARGE, THERE IS NO
WARRANTY FOR THE DESIGN, TO THE EXTENT PERMITTED BY APPLICABLE LAW. EXCEPT
WHEN OTHERWISE STATED IN WRITING THE COPYRIGHT HOLDERS AND/OR OTHER PARTIES
PROVIDE THE DESIGN "AS IS" WITHOUT WARRANTY OF ANY KIND, EITHER EXPRESSED
OR IMPLIED, INCLUDING, BUT NOT LIMITED TO, THE IMPLIED WARRANTIES OF
MERCHANTABILITY AND FITNESS FOR A PARTICULAR PURPOSE. THE ENTIRE RISK AS TO
THE QUALITY AND PERFORMANCE OF THE DESIGN IS WITH YOU. SHOULD THE DESIGN
PROVE DEFECTIVE, YOU ASSUME THE COST OF ALL NECESSARY SERVICING, REPAIR OR
CORRECTION.

IN NO EVENT UNLESS REQUIRED BY APPLICABLE LAW OR AGREED TO IN WRITING WILL
ANY COPYRIGHT HOLDER, OR ANY OTHER PARTY WHO MAY MODIFY AND/OR REDISTRIBUTE
THE DESIGN AS PERMITTED ABOVE, BE LIABLE TO YOU FOR DAMAGES, INCLUDING ANY
GENERAL, SPECIAL, INCIDENTAL OR CONSEQUENTIAL DAMAGES ARISING OUT OF THE
USE OR INABILITY TO USE THE DESIGN (INCLUDING BUT NOT LIMITED TO LOSS OF
DATA OR DATA BEING RENDERED INACCURATE OR LOSSES SUSTAINED BY YOU OR THIRD
PARTIES OR A FAILURE OF THIS MATERIAL TO OPERATE WITH ANY OTHER SYSTEMS OR
SOFTWARE), EVEN IF SUCH HOLDER OR OTHER PARTY HAS BEEN ADVISED OF THE
POSSIBILITY OF SUCH DAMAGES.

You agree not to download or use the hardware designs or related software
in any state or country that does not allow the exclusion or limitation of
liability for consequential or incidental damages.

The ideas for the hardware licensing are taken from the GNU General Pubic
license for software. The agreement not to download in any state or country
that does not allow exclusion or limitation of liability was copied from
Metachip (Australia) Pty. Ltd. (Bitscope).

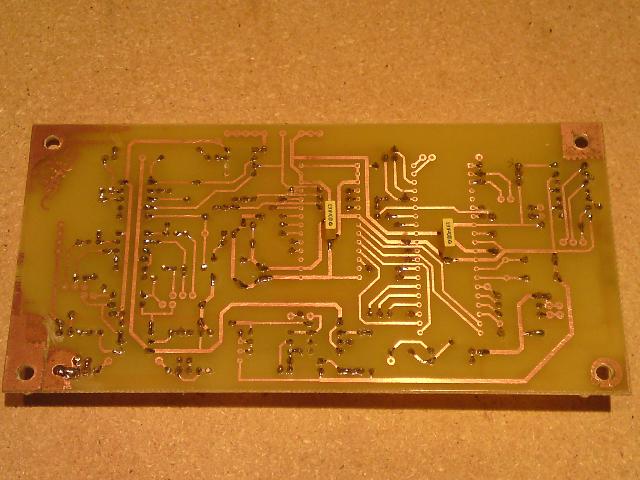
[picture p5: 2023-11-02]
Pictures/karolysimon3.jpg

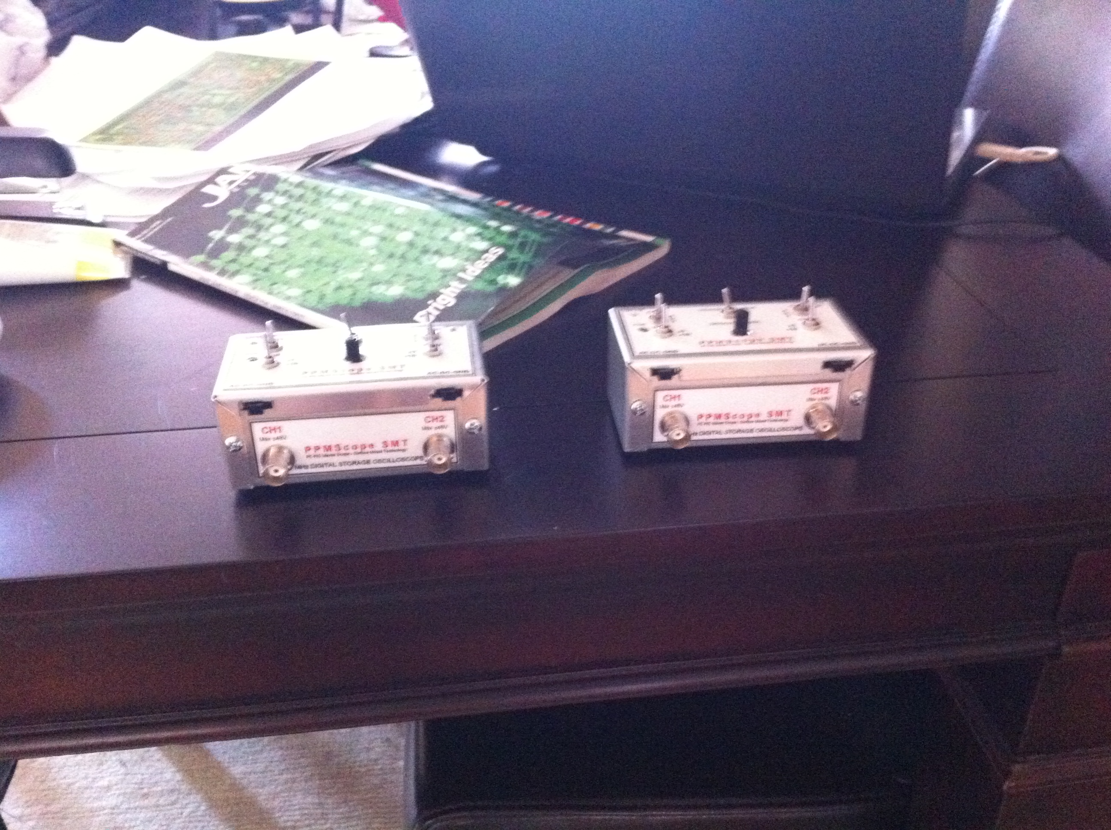
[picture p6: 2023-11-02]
Pictures/Mark Burton 20131015 083018.jpg

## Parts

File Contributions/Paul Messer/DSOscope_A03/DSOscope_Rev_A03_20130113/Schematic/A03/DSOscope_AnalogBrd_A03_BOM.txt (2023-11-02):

====+  Parts List for DSOscope_AnalogBrd_A03.dsn  +====

Reference_Designator(s)       Qty   Description                                           PN_Digi-Key           PN_Jameco       
---------------------------   ---   ---------------------------------------------------   -------------------   ----------------

C1,C3                           2   0.1uF 10% 100V X7R 1206                               478-1529-1-ND          
C2,C4                           2   100pF 5% 100V C0G 0805                                399-1123-1-ND          
C5,C6,C7,C8,C9,C10,C11,C12      8   1.0uF +80% -20% 25V Y5V 0805                          311-1358-1-ND          
C13,C16,C17                     3   10uF +80% -20% 16V Y5V 0805                           490-3347-1-ND          
C14,C15                         2   10pF 5% 50V C0G 0603                                  399-1049-1-ND          
C18                             1   0.1uF 10% 50V X7R 0805                                399-1170-1-ND          
D1,D2,D6,D7                     4   BAP50-03 Pin Diode 50V 50mA: SOD-323                  568-1916-1-ND          
D3,D8                           2   MMBD7000 Signal Diode Dual: SOT-23                                          656309 
D4,D5,D9,D10                    4   MMSZ5237B Zener Diode 8.2V 0.5W: SOD-123              MMSZ5237B-FDICT-ND     
D11                             1   LED Red : T1 3/4                                                            333489 
J1,J2                           2   Terminal Block Screw 2 pin 0.2 space                  ED2609-ND              
J3                              1   1 x 18 Sq Pin Socket 0.025 pin 0.1 space              S7051-ND               
J4                              1   1 x 7 Sq Pin Socket 0.025 pin 0.1 space               S7040-ND               
R1,R14                          2   10.0 1/8W 1% 0805                                     311-10.0CRCT-ND        
R2,R3,R15,R16,R33,R34           6   1.00M 1/8W 1% 0805                                    311-1.00MCRCT-ND       
R4,R7,R9,R25,R27,R30,R35,       9   1.00K 1/8W 1% 0805                                    311-1.00KCRCT-ND       
R36,R37                       
R5,R18                          2   3.90K 1/8W 1% 0805                                    311-3.90KCRCT-ND       
R6,R19,R26                      3   100K 1/8W 1% 0805                                     311-100KCRCT-ND        
R8,R21                          2   2.61K 1/8W 1% 0805                                    311-2.61KCRCT-ND       
R10,R23                         2   110K 1/8W 1% 0805                                     311-110KCRCT-ND        
R13,R31                         2   10K Pot 0.5W 25Turn                                   490-2875-ND            
R28                             1   680 1/8W 1% 0805                                      311-680CRCT-ND         
R29                             1   10K Pot Vertical 0.125W                               CT2265-ND              
R32                             1   DNI Do Not Install - 1/8W 1% 0805                     No P/N                 
SW1,SW5                         2   DP3T EG2322 Slide Switch Right Angle                  EG1948-ND              
SW2,SW4,SW6                     3   DPDT Subminiature (on-on)                                                   75977 
SW3,SW7                         2   DPDT Subminiature (on-off-on)                                               138907 
U1,U2,U3                        3   TLE2082 Dual JFET OP AMP: SOIC-8                      296-1343-1-ND          
U4                              1   LM311 Single Comparator: SOIC-8                       497-1569-1-ND          

====+  End of Parts List for DSOscope_AnalogBrd_A03.dsn  +====

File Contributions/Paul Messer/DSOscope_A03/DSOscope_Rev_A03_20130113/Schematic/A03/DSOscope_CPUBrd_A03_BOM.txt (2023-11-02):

====+  Parts List for DSOscope_CPUBrd_A03.dsn  +====

Reference_Designator(s)       Qty   Description                                           PN_Digi-Key           PN_Jameco       
---------------------------   ---   ---------------------------------------------------   -------------------   ----------------

BOM_1                           1   Cabinet Aluminum 4.0"x2.2"x1.6" BOM Only Part         HM609-ND               
BOM_2,BOM_3,BOM_4,BOM_5         4   Feet - Bumpons BOM Only Part                          SJ5012-0-ND           142658 
BOM_6,BOM_7                     2   BNC Jack 50 Ohm Panel Mount BOM Only Part                                   355178 
BOM_8,BOM_9                     2   RG174/U Cable - Cut to Length 4.5" BOM Only Part                            644818 
BOM_10,BOM_11                   2   Card Guide - Custom BOM Only Part                                            
BOM_12                          1   Top Cabinet Label - Custom BOM Only Part                                     
BOM_13                          1   Front Cabinet Label - Custom BOM Only Part                                   
BOM_14                          1   Rear Cabinet Label - Custom BOM Only Part                                    
C1,C5,C6,C22                    4   1.0uF +80% -20% 25V Y5V 0805                          311-1358-1-ND          
C2                              1   470nF 10% 16V X7R 0805                                311-1364-1-ND          
C3,C4                           2   22pF 5% 50V C0G 0603                                  399-1053-1-ND          
C7,C24,C25                      3   10uF +80% -20% 16V Y5V 0805                           490-3347-1-ND          
C8,C10,C12,C16                  4   100uF 20% 35V Alum Radial                             P5165-ND               
C9,C14,C15,C19,C20              5   0.1uF 10% 50V X7R 0805                                399-1170-1-ND          
C11                             1   0.001uF 10% 50V X7R 0805                              399-1147-1-ND          
C13,C18                         2   470uF 20% 35V Alum Radial                             493-1084-ND            
C17                             1   1500pF 10% 100V X7R 0805                              445-4429-1-ND          
C21,C23                         2   330pF 5% 50V C0G 0603                                 399-1068-1-ND          
D1                              1   1N4148 Signal Diode: DO-35-SMT                        1N4148FS-ND            
D2                              1   MMSZ5232B Zener Diode 5.6V 0.5W: SOD-123              MMSZ5232B-FDICT-ND     
D4,D5                           2   1N5819 Schottky Diode: DO-41                          1N5819DICT-ND         177965 
F1                              1   0.5A PolySwitch Resetable Fuse                        MINISMDC050FCT-ND      
J1                              1   Cut Strap 1 x 2 0.025 pin 0.1 space                                          
J2                              1   1 x 7 Square Pin Conn 0.025 pin 0.1 space             S1211E-36-ND           
J3                              1   1 x 18 Square Pin Conn 0.025 pin 0.1 space            S1211E-36-ND           
J4                              1   1 x 6 Square Pin Conn 0.025 pin 0.1 space             S1211E-36-ND           
J5                              1   USB-B Right Angle Thru Hole                           151-1121-ND            
L1,L2                           2   100uH Inductor: 0.80A Shielded SMT                    308-1424-1-ND          
L3,L4                           2   10uH Inductor: 0.70A Shielded SMT 1210                490-5340-1-ND          
R2,R3,R5,R12,R14                5   1.00K 1/8W 1% 0805                                    311-1.00KCRCT-ND       
R4,R6,R7,R8,R9,R33,R34,R35      8   10.0K 1/8W 1% 0805                                    311-10.0KCRCT-ND       
R17,R18,R32                     3   DNI Do Not Install - 1/8W 1% 0805                     No P/N                 
R21,R22,R27,R28                 4   1.00 1/8W 1% 0805                                     311-1.00CRCT-ND        
R23                             1   100 1/8W 1% 0805                                      311-100CRCT-ND         
R24,R31                         2   8.20K 1/8W 1% 0805                                    311-8.20KCRCT-ND       
R25,R26,R29,R30                 4   470 1/8W 1% 0805                                      311-470CRCT-ND         
U1                              1   MAX118 ADC 8 Ch 1MHz: SSOP-28                         MAX118CAI+-ND          
U2                              1   PIC16F887 MicroController: TQFP-44                    PIC16F887-I/PT-ND      
U4,U5                           2   MC34063A Switching Regulator: SOIC-8                  MC34063ADR2GOSCT-ND    
X1                              1   20.00MHz XTAL: HC49 Vertical                          X439-ND                

====+  End of Parts List for DSOscope_CPUBrd_A03.dsn  +====

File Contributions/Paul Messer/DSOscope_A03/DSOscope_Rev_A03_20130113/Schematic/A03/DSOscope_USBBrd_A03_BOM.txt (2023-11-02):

====+  Parts List for DSOscope_USBBrd_A03.dsn  +====

Reference_Designator(s)       Qty   Description                                           PN_Digi-Key           PN_Jameco       
---------------------------   ---   ---------------------------------------------------   -------------------   ----------------

C1                              1   1.0uF +80% -20% 25V Y5V 0805                          311-1358-1-ND          
C2                              1   4.7uF 10% 16V X5R 0805                                445-7640-1-ND          
C3                              1   0.1uF 10% 50V X7R 0805                                399-1170-1-ND          
D1                              1   LED Green : SMT 1206                                                        2039902 
D2                              1   LED Red : SMT 1206                                                          1556414 
L1                              1   Ferrite Bead SMT 1000 ohm:100MHz                      445-1559-1-ND          
P1                              1   1 x 6 Sq Pin Socket 0.025 pin 0.1 space               S7039-ND               
R1,R2                           2   1.00K 1/8W 1% 0805                                    311-1.00KCRCT-ND       
R3,R4,R5,R10                    4   DNI Do Not Install - 1/8W 1% 0805                     No P/N                 
R6                              1   10.0K 1/8W 1% 0805                                    311-10.0KCRCT-ND       
R7,R8,R9                        3   220 1/8W 1% 0805                                      311-220CRCT-ND         
U1                              1   FT232RL USB UART: SSOP-28                             768-1007-1-ND          

====+  End of Parts List for DSOscope_USBBrd_A03.dsn  +====

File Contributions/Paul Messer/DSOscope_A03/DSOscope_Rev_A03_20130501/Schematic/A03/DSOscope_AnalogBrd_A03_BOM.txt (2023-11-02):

====+  Parts List for DSOscope_AnalogBrd_A03.dsn  +====

Reference_Designator(s)       Qty   Description                                           PN_Digi-Key           PN_Jameco       
---------------------------   ---   ---------------------------------------------------   -------------------   ----------------

C1,C3                           2   0.1uF 10% 100V X7R 1206                               478-1529-1-ND          
C2,C4                           2   100pF 5% 100V C0G 0805                                399-1123-1-ND          
C5,C6,C7,C8,C9,C10,C11,C12      8   1.0uF +80% -20% 25V Y5V 0805                          311-1358-1-ND          
C13,C16,C17                     3   10uF +80% -20% 16V Y5V 0805                           490-3347-1-ND          
C14,C15                         2   DNI Do Not Install - 0603                             No P/N                 
C18                             1   0.1uF 10% 50V X7R 0805                                399-1170-1-ND          
D1,D2,D6,D7                     4   BAP50-03 Pin Diode 50V 50mA: SOD-323                  568-1916-1-ND          
D3,D8                           2   MMBD7000 Signal Diode Dual: SOT-23                                          656309 
D4,D5,D9,D10                    4   MMSZ5237B Zener Diode 8.2V 0.5W: SOD-123              MMSZ5237B-FDICT-ND     
D11                             1   LED Red : T1 3/4                                                            333489 
J1,J2                           2   Terminal Block Screw 2 pin 0.2 space                  ED2609-ND              
J3                              1   1 x 18 Sq Pin Socket 0.025 pin 0.1 space              S7051-ND               
J4                              1   1 x 7 Sq Pin Socket 0.025 pin 0.1 space               S7040-ND               
R1,R14                          2   10.0 1/8W 1% 0805                                     311-10.0CRCT-ND        
R2,R3,R15,R16,R33,R34           6   1.00M 1/8W 1% 0805                                    311-1.00MCRCT-ND       
R4,R6,R7,R9,R11,R12,R17,       17   1.00K 1/8W 1% 0805                                    311-1.00KCRCT-ND       
R19,R20,R22,R24,R25,R27,
R30,R35,R36,R37                       
R5,R18                          2   3.90K 1/8W 1% 0805                                    311-3.90KCRCT-ND       
R26                             1   100K 1/8W 1% 0805                                     311-100KCRCT-ND        
R8,R21                          2   2.61K 1/8W 1% 0805                                    311-2.61KCRCT-ND       
R10,R23                         2   110K 1/8W 1% 0805                                     311-110KCRCT-ND        
R13,R31                         2   10K Pot 0.5W 25Turn                                   490-2875-ND            
R28                             1   680 1/8W 1% 0805                                      311-680CRCT-ND         
R29                             1   10K Pot Vertical 0.125W                               CT2265-ND              
R32                             1   DNI Do Not Install - 0805                             No P/N                 
SW1,SW5                         2   DP3T EG2322 Slide Switch Right Angle                  EG1948-ND              
SW2,SW4,SW6                     3   DPDT Subminiature (on-on)                                                   75977 
SW3,SW7                         2   DPDT Subminiature (on-off-on)                                               138907 
U1,U2,U3                        3   TLE2082 Dual JFET OP AMP: SOIC-8                      296-1343-1-ND          
U4                              1   LM311 Single Comparator: SOIC-8                       497-1569-1-ND          

====+  End of Parts List for DSOscope_AnalogBrd_A03.dsn  +====

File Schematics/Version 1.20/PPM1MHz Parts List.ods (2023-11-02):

Reference | Quantity | Name | Description | Package | Manufacturer | Manufacturer Part # | Digikey Part # | Jameco Part # | Newark Part # | Allied Elec Part # | Mouser Part # | Datasheet | Least Cost Source | Cost | Extended Cost
BR1 | 1 | BR1 | Small Bridge Rect. | 4EDIP300 | Vishay | DF01M-E3/45 | DF01M-E3/45GI-ND | 103000 | 65K2443 | 70015980 | 625-DF01M-E3 | http://www.vishay.com/docs/88571/dfm.pdf | Jameco | $0.29 | $0.29
C1, C5 | 2 | 20p | Capacitor | C300 | MULTICOMP | S200K25SL0N63L6R | 1265PH-ND | 332322 | 46P6462 | 70079497 | 140-50N5-200J-RC | http://www.newark.com/pdfs/datasheets/spc/Ta-1072.pdf | Newark | $0.06 | $0.12
C10, C11 | 2 | 1000u | Capacitor (different style) | RAD-394 | Nichicon | UVR1E102MPD | 493-1065-ND | 158298 | 69K7911 | 70112169 | 647-UVZ1E102MPD1TD | http://www.nichicon.co.jp/english/products/pdfs/e-vr.pdf | Mouser | $0.25 | $0.50
C12, C13, C14 | 3 | 100u | Capacitor (different style) | RAD-248 | Illinois Capacitor | 107CKS016M | 399-6106-ND | 93761 | 69K7858 | 70111684 | 871-B41827A4107M000 | http://www.alliedelec.com/images/products/datasheets/bm/ILLINOIS_CAPACITOR/70111684.pdf | Allied | $0.04 | $0.12
C2, C3, C4 | 3 | 100n | Capacitor | C300 | Vishay | K104K10X7RF53L2 | 490-3859-ND | 25523 | 95C0980 | 70122993 | 21RZ310-RC | http://www.alliedelec.com/images/products/datasheets/bm/BC_COMPONENTS_VISHAY/70121924.pdf | Allied | $0.05 | $0.15
C6, C7, C8 | 3 | 4.7u | Capacitor | RAD-248 | Lelon | REA4R7M1JBK-0511P | P935-ND | 31002 | 23K3615 | 70112196 | 140-REA4R7M1JBK0511P | http://www.lelon.com.tw/down.php?f=%2Ffile%2F21.pdf&n=REA.pdf (http://www.lelon.com.tw/down.php?f=/file/21.pdf&n=REA.pdf) | Mouser | $0.06 | $0.18
C9 | 1 | 0.47u | Capacitor | C300 |  |  |  |  |  |  |  |  |  |  | $0.00
D1, D2, D3, D4, D5, D6, D7, D8, D9, D10 | 10 | N4148 | Diode | DO-35 |  |  |  |  |  |  |  |  |  |  | $0.00
F1 | 1 | FUSE1A | Fuse, small |  |  |  |  |  |  |  |  |  |  |  | $0.00
Q1 | 1 | N3904 | Bipolar transistor, small | TO-92-A |  |  |  |  |  |  |  |  |  |  | $0.00
R1, R10, R11, R16, R21, R22, R23, R25, R27, R32, R33, R34, R35, R38, R39, R44, R45, R5 | 18 | 1k | Small Resistor | RC05 |  |  |  |  |  |  |  |  |  |  | $0.00
R12, R13, R14, R3, R36, R37, R4, R41, R43, R6, R9 | 11 | 10k | Small Resistor | RC05 |  |  |  |  |  |  |  |  |  |  | $0.00
R15, R26 | 2 | 3.9k | Small Resistor | RC05 |  |  |  |  |  |  |  |  |  |  | $0.00
R17, R19, R28, R30, R47, R48, R49 | 7 | 100k | Small Resistor | RC05 |  |  |  |  |  |  |  |  |  |  | $0.00
R18, R29 | 2 | 33k | Small Resistor | RC05 |  |  |  |  |  |  |  |  |  |  | $0.00
R2 | 1 | 10k | Small Resistor | RC07 |  |  |  |  |  |  |  |  |  |  | $0.00
R20, R31 | 2 | 2.7k | Small Resistor | RC05 |  |  |  |  |  |  |  |  |  |  | $0.00
R24 | 1 | POT10k | Small Var. Resistor | POT 3386P |  |  |  |  |  |  |  |  |  |  | $0.00
R40 | 1 | 4.7k | Small Resistor | RC05 |  |  |  |  |  |  |  |  |  |  | $0.00
R42 | 1 | 10k | Small Var. Resistor | Panelmount |  |  |  |  |  |  |  |  |  |  | $0.00
R46 | 1 | 220 | Small Resistor | RC05 |  |  |  |  |  |  |  |  |  |  | $0.00
S1A, S1B, S2A, S2B | 4 | ACDCMode | Single Pole Switch | Panelmount DPDT |  |  |  |  |  |  |  |  |  |  | $0.00
S3, S4 | 2 | Gain | 2 pole 3 pos. switch | Panelmount DP3T |  |  |  |  |  |  |  |  |  |  | $0.00
T1 | 1 | 120:24.9 | Center tap Transformer |  |  |  |  |  |  |  |  |  |  |  | $0.00
U1 | 1 | PIC16F877A | PIC microcontroller | 40DIP600 |  |  |  |  |  |  |  |  |  |  | $0.00
U2 | 1 | MAX118 | ADC - 1 MHz | 28DIP600 |  |  |  |  |  |  |  |  |  |  | $0.00
U3, U4, U5 | 3 | TLE2082 | Dual Low Noise Op-Amp | 8DIP300 |  |  |  |  |  |  |  |  |  |  | $0.00
U6, U7 | 2 | LM311 | LM311 | 8DIP300 |  |  |  |  |  |  |  |  |  |  | $0.00
U8 | 1 | 7407 | Hex Buffers | 14DIP300 |  |  |  |  |  |  |  |  |  |  | $0.00
U9 | 1 | LM7805 | Fixed V 3-term reg | TO-220 |  |  |  |  |  |  |  |  |  |  | $0.00
U10 | 1 | LM7812 | Fixed V 3-term reg | TO-220 |  |  |  |  |  |  |  |  |  |  | $0.00
U11 | 1 | LM7912 | Fixed V 3-term reg | TO-220 |  |  |  |  |  |  |  |  |  |  | $0.00
X1 | 1 | 20MHz | Crystal | CK60 |  |  |  |  |  |  |  |  |  |  | $0.00
Z1 | 1 | USBB | USB B Connector | Panelmount USBB |  |  |  |  |  |  |  |  |  |  | $0.00
 |  |  |  |  |  |  |  |  |  |  |  |  |  | Total | $1.36

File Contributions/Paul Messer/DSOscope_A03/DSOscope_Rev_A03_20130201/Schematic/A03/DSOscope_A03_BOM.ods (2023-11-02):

Reference Designators | Qty | Description | PN Digi-Key | PN Jameco
D1 | 10 | LED Green : SMT 1206 |  | 2039902
D2 | 10 | LED Red : SMT 1206 |  | 1556414
D3,D8 | 20 | MMBD7000 Signal Diode Dual: SOT-23 | MMBD7000-E3-08CT-ND | 656309 | Digikey, Jameco out of stock
BOM_8,BOM_9 | 20 | RG174/U Cable - Cut to Length 4.5" BOM Only Part |  | 644818
BOM_6,BOM_7 | 20 | BNC Jack 50 Ohm Panel Mount BOM Only Part |  | 355178
D11 | 10 | LED Red : T1 3/4 |  | 333489
D4,D5 | 20 | 1N5819 Schottky Diode: DO-41 | 1N5819DICT-ND | 177965 | Jameco
BOM_2,BOM_3,BOM_4,BOM_5 | 40 | Feet - Bumpons BOM Only Part | SJ5012-0-ND | 142658 | Digikey
SW3,SW7 | 20 | DPDT Subminiature (on-off-on) |  | 138907 | 1/16 holes
SW2,SW4,SW6 | 30 | DPDT Subminiature (on-on) |  | 75977 | 1/16 holes
J5 | 10 | USB-B Right Angle Thru Hole | 151-1121-ND |  | 3/32 holes
D1 | 10 | 1N4148 Signal Diode: DO-35-SMT | 1N4148FS-ND
U1,U2,U3 | 30 | TLE2082 Dual JFET OP AMP: SOIC-8 | 296-13622-1-ND |  | Substituted Part
L1,L2 | 20 | 100uH Inductor: 0.80A Shielded SMT | 308-1424-1-ND
R21,R22,R27,R28 | 40 | 1.00 1/8W 1% 0805 | 311-1.00CRCT-ND
R2,R3,R5,R12,R14 | 160 | 1.00K 1/8W 1% 0805 | 311-1.00KCRCT-ND
R2,R3,R15,R16,R33,R34 | 60 | 1.00M 1/8W 1% 0805 | 311-1.00MCRCT-ND
R1,R14 | 20 | 10.0 1/8W 1% 0805 | 311-10.0CRCT-ND
R4,R6,R7,R8,R9,R33,R34,R35 | 90 | 10.0K 1/8W 1% 0805 | 311-10.0KCRCT-ND
R23 | 10 | 100 1/8W 1% 0805 | 311-100CRCT-ND
R6,R19,R26 | 30 | 100K 1/8W 1% 0805 | 311-100KCRCT-ND
R10,R23 | 20 | 110K 1/8W 1% 0805 | 311-110KCRCT-ND
C1,C5,C6,C22 | 130 | 1.0uF +80% -20% 25V Y5V 0805 | 311-1358-1-ND
C2 | 10 | 470nF 10% 16V X7R 0805 | 311-1364-1-ND
R8,R21 | 20 | 2.61K 1/8W 1% 0805 | 311-2.61KCRCT-ND
R7,R8,R9 | 30 | 220 1/8W 1% 0805 | 311-220CRCT-ND
R5,R18 | 20 | 3.90K 1/8W 1% 0805 | 311-3.90KCRCT-ND
R25,R26,R29,R30 | 40 | 470 1/8W 1% 0805 | 311-470CRCT-ND
R28 | 10 | 680 1/8W 1% 0805 | 311-680CRCT-ND
R24,R31 | 20 | 8.20K 1/8W 1% 0805 | 311-8.20KCRCT-ND
C14,C15 | 20 | 10pF 5% 50V C0G 0603 | 399-1049-1-ND
C3,C4 | 20 | 22pF 5% 50V C0G 0603 | 399-1053-1-ND
C21,C23 | 20 | 330pF 5% 50V C0G 0603 | 399-1068-1-ND
C2,C4 | 20 | 100pF 5% 100V C0G 0805 | 399-1123-1-ND
C11 | 10 | 0.001uF 10% 50V X7R 0805 | 399-1147-1-ND
C9,C14,C15,C19,C20 | 70 | 0.1uF 10% 50V X7R 0805 | 399-1170-1-ND
L1 | 10 | Ferrite Bead SMT 1000 ohm:100MHz | 445-1559-1-ND
C17 | 10 | 1500pF 10% 100V X7R 0805 | 445-4429-1-ND
C2 | 10 | 4.7uF 10% 16V X5R 0805 | 445-7640-1-ND
C1,C3 | 20 | 0.1uF 10% 100V X7R 1206 | 478-1529-1-ND
R13,R31 | 20 | 10K Pot 0.5W 25Turn | 490-2875-ND
C7,C24,C25 | 60 | 10uF +80% -20% 16V Y5V 0805 | 490-3886-1-ND |  | Substituted Part
L3,L4 | 20 | 10uH Inductor: 0.70A Shielded SMT 1210 | 490-5340-1-ND
C13,C18 | 20 | 470uF 20% 35V Alum Radial | 493-1084-ND
U4 | 10 | LM311 Single Comparator: SOIC-8 | 497-1569-1-ND
D1,D2,D6,D7 | 40 | BAP50-03 Pin Diode 50V 50mA: SOD-323 | 568-1916-1-ND
U1 | 10 | FT232RL USB UART: SSOP-28 | 768-1007-1-ND
R29 | 10 | 10K Pot Vertical 0.125W | CT2265-ND |  | 1/16, 7/64
SW1,SW5 | 20 | DP3T EG2322 Slide Switch Right Angle | EG1948-ND
BOM_1 | 10 | Cabinet Aluminum 4.0"x2.2"x1.6" BOM Only Part | HM609-ND
U1 | 10 | MAX118 ADC 8 Ch 1MHz: SSOP-28 | MAX118CAI+-ND |  | Ordered from Maxim
U4,U5 | 20 | MC34063A Switching Regulator: SOIC-8 | MC34063ADR2GOSCT-ND
F1 | 10 | 0.5A PolySwitch Resetable Fuse | MINISMDC050FCT-ND
D2 | 10 | MMSZ5232B Zener Diode 5.6V 0.5W: SOD-123 | MMSZ5232B-FDICT-ND
D4,D5,D9,D10 | 40 | MMSZ5237B Zener Diode 8.2V 0.5W: SOD-123 | MMSZ5237B-FDICT-ND
C8,C10,C12,C16 | 40 | 100uF 20% 35V Alum Radial | P5165-ND
U2 | 10 | PIC16F887 MicroController: TQFP-44 | PIC16F887-I/PT-ND
J2 | 10 | 1 x 7 Square Pin Conn 0.025 pin 0.1 space | S1211E-36-ND
P1 | 10 | 1 x 6 Sq Pin Socket 0.025 pin 0.1 space | S7039-ND
J4 | 10 | 1 x 7 Sq Pin Socket 0.025 pin 0.1 space | S7040-ND
J3 | 10 | 1 x 18 Sq Pin Socket 0.025 pin 0.1 space | S7051-ND
X1 | 10 | 20.00MHz XTAL: HC49 Vertical | X439-ND

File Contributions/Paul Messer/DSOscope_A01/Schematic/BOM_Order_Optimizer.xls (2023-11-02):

Project Name: |  | Project Name Here |  |  |  |  |  |  |  |  |  |  |  |  |  | Page1 of 1
Date: |  | Project Date Here
Revision: |  | Revision Number Here
Inventory Status as of: |  | Inventory Status Date Here
* * * * * Project Name Here Rev. Revision Number Here BOM * * * * * |  |  |  |  |  | Materials Mgmt |  |  | * * * * * * * * * * Automated Procurement Optimizer * * * * * * * * * *
 |  |  |  |  |  | Build Quantity = |  | 1 | Supplier A = | Digi-Key |  |  | Supplier B = | Jameco
 |  |  |  |  |  |  |  | Minimum Quantity to Order
Item No. | Quantity used per Assembly | Part | Description | PackageType | Reference Designators | Inventory Status |  |  | PN_Digi-Key | Cost Each | Assy Cost | Order Cost | PN_Jameco | Cost Each | Assy Cost | Order Cost
1 | 1 |  |  |  |  | 0 | -1 | 1 |  |  | $0.0000 |  |  |  | $0.0000
2 | 1 |  |  |  |  | 1 | 0 | - - - |  |  | $0.0000 |  |  |  | $0.0000
3 | 1 |  |  |  |  | 2 | 1 | - - - |  |  | $0.0000 |  |  |  | $0.0000
 |  |  |  |  |  | 0 | 0 | - - - |  |  | $0.0000 |  |  |  | $0.0000
 |  |  |  |  |  | 0 | 0 | - - - |  |  | $0.0000 |  |  |  | $0.0000
 |  |  |  |  |  | 0 | 0 | - - - |  |  | $0.0000 |  |  |  | $0.0000
 |  |  |  |  |  | 0 | 0 | - - - |  |  | $0.0000 |  |  |  | $0.0000
 |  |  |  |  |  | 0 | 0 | - - - |  |  | $0.0000 |  |  |  | $0.0000
 |  |  |  |  |  | 0 | 0 | - - - |  |  | $0.0000 |  |  |  | $0.0000
 |  |  |  |  |  | 0 | 0 | - - - |  |  | $0.0000 |  |  |  | $0.0000
 |  |  |  |  |  | 0 | 0 | - - - |  |  | $0.0000 |  |  |  | $0.0000
 |  |  |  |  |  | 0 | 0 | - - - |  |  | $0.0000 |  |  |  | $0.0000
 |  |  |  |  |  | 0 | 0 | - - - |  |  | $0.0000 |  |  |  | $0.0000
 |  |  |  |  |  | 0 | 0 | - - - |  |  | $0.0000 |  |  |  | $0.0000
 |  |  |  |  |  | 0 | 0 | - - - |  |  | $0.0000 |  |  |  | $0.0000
 |  |  |  |  |  | 0 | 0 | - - - |  |  | $0.0000 |  |  |  | $0.0000
 |  |  |  |  |  | 0 | 0 | - - - |  |  | $0.0000 |  |  |  | $0.0000
 |  |  |  |  |  | 0 | 0 | - - - |  |  | $0.0000 |  |  |  | $0.0000
 |  |  |  |  |  | 0 | 0 | - - - |  |  | $0.0000 |  |  |  | $0.0000
 |  |  |  |  |  | 0 | 0 | - - - |  |  | $0.0000 |  |  |  | $0.0000
 |  |  |  |  |  | 0 | 0 | - - - |  |  | $0.0000 |  |  |  | $0.0000
 |  |  |  |  |  | 0 | 0 | - - - |  |  | $0.0000 |  |  |  | $0.0000
 |  |  |  |  |  | 0 | 0 | - - - |  |  | $0.0000 |  |  |  | $0.0000
 |  |  |  |  |  | 0 | 0 | - - - |  |  | $0.0000 |  |  |  | $0.0000
 |  |  |  |  |  | 0 | 0 | - - - |  |  | $0.0000 |  |  |  | $0.0000
 |  |  |  |  |  | 0 | 0 | - - - |  |  | $0.0000 |  |  |  | $0.0000
 |  |  |  |  |  | 0 | 0 | - - - |  |  | $0.0000 |  |  |  | $0.0000
 |  |  |  |  |  | 0 | 0 | - - - |  |  | $0.0000 |  |  |  | $0.0000
 |  |  |  |  |  | 0 | 0 | - - - |  |  | $0.0000 |  |  |  | $0.0000
 |  |  |  |  |  | 0 | 0 | - - - |  |  | $0.0000 |  |  |  | $0.0000
 |  |  |  |  |  | 0 | 0 | - - - |  |  | $0.0000 |  |  |  | $0.0000
 |  |  |  |  |  | 0 | 0 | - - - |  |  | $0.0000 |  |  |  | $0.0000
 |  |  |  |  |  | 0 | 0 | - - - |  |  | $0.0000 |  |  |  | $0.0000
 |  |  |  |  |  | 0 | 0 | - - - |  |  | $0.0000 |  |  |  | $0.0000
 |  |  |  |  |  | 0 | 0 | - - - |  |  | $0.0000 |  |  |  | $0.0000
 |  |  |  |  |  | 0 | 0 | - - - |  |  | $0.0000 |  |  |  | $0.0000
 |  |  |  |  |  | 0 | 0 | - - - |  |  | $0.0000 |  |  |  | $0.0000
 |  |  |  |  |  | 0 | 0 | - - - |  |  | $0.0000 |  |  |  | $0.0000
 |  |  |  |  |  | 0 | 0 | - - - |  |  | $0.0000 |  |  |  | $0.0000
 |  |  |  |  |  | 0 | 0 | - - - |  |  | $0.0000 |  |  |  | $0.0000
 |  |  |  |  |  | 0 | 0 | - - - |  |  | $0.0000 |  |  |  | $0.0000
 |  |  |  |  |  | 0 | 0 | - - - |  |  | $0.0000 |  |  |  | $0.0000
 |  |  |  |  |  | 0 | 0 | - - - |  |  | $0.0000 |  |  |  | $0.0000
 |  |  |  |  |  |  |  |  |  |  |  |  |  |  | $0.0000
 |  |  |  |  |  |  |  |  | Individual Assembly Cost Less Unsupported Parts |  | $0.00 |  | Individual Assembly Cost Less Unsupported Parts |  | $0.00
 |  |  |  |  |  |  |  |  | Optimized Order Quantity Cost |  |  | $0.00 | Optimized Order Quantity Cost |  |  | $0.00
NOTES: | 1 |  |  |  |  |  | Inventory Threshold Value Settings
 | 2 |  |  |  |  |  |  | > 0 | Sufficient quantity in stock
 | 3 |  |  |  |  |  |  | 0 | Marginal quantity in stock
 |  |  |  |  |  |  |  | -1 | Insufficient quantity in stock

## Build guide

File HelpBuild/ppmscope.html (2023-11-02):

### PPM Scope for Windows (Download)

PPMScope is a do-it-yourself oscilloscope design with a maximum sample rate of 1 MHz (bandwidth of 500 kHz). The hardware is based on the PIC16F877A Microcontroller. I am creating this tool for my general use at home, but I thought others may benefit from the software and schematics. The human interface to the oscilloscope is both a part of the box (knobs, switches, etc) and through a PC program written in C for Windows.

The scope interfaces with the PC and communicates with the Windows software to display the captured waveform in the both the time and frequency domains. The design combines a high frequency analog stage with AC/DC coupling and three gains, a MAX118 digital to analog converter, a trigger circuit, a PIC16F877A microcontroller, and some PC interfacing hardware.

Screenshots of the program and pictures of the oscilloscope are below.

 Screenshot of the Oscilloscope program
 |  |  |  | 
Click on small image to enlarge

#### Specifications and Goal Feature List

| Current Version (v.2.14) | Goal Version
Sample Rate | Variable, single shot 1 MHz max, interlaced 417 kHz max, time equivalent 5 MHz max | Variable, single shot 1 MHz max, interlaced 500 kHz max, time equivalent 5 MHz max
Bandwidth | 500 kHz | 500 kHz
Number of Channels | Two | Two
Sample Depth | 256 bytes per channel, 128 bytes per channel when interlaced | 256 bytes per channel, 128 bytes per channel when interlaced
Sample Modes | Single shot, interlaced channel, and time equivalent | Single shot, interlaced channel, and time equivalent
Calibration | Voltage offset | Voltage per division and voltage offset calibration
Configuration Settings | Configuration of default and saving of settings for future use | Configuration of default and saving of settings for future use
Hardware Connection | Any parallel or serial port | Any parallel, serial, or USB port
Coupling | AC and DC, reflected on PC | AC and DC, reflected on PC
Channel gain | Gain of 1, 2, and 5, reflected on PC | Gain of 1, 2, and 5, reflected on PC
Trigger | Variable level, slope, and timing | Variable level, slope, and timing
Frequency Spectrum | Yes | Yes with user selected sampling windows
Waveform Reconstruction | Triangle, square, point, and sinc | Triangle, square, point, and sinc
XY view | Yes | Yes
Channel offset and volt per division settings | Yes | Yes
Cursors | Yes | Yes
Math functions | Addition, subtraction, auto period, auto peak-to-peak, etc. | Addition, subtraction, auto period, auto peak-to-peak, etc.
Waveform export | Comma delimited | Bitmap and comma delimited
Waveform logging | Comma delimited logfile containing waveform and measurement information | Comma delimited logfile containing waveform and measurement information

#### Release Notes

Release Notes for version 2.141 build 3/30/2012

- Correction of bug. The program would sometimes freeze when turning the trigger off.
- Fine tuning of waveform and measurement logging.
- Feedback of modes on the toolbar using depressed buttons.
- Upgrade of software license to GPL v3.
- Ground plane added to PCB layout.
- Parts list added for version 1.2 of the hardware.

Release Notes for version 2.14 build 12/12/2011

- Addition of user configurable parallel port.
- Addition of serial port interface.
- Addition of hardware testing dialog.
- Change to the firmware and software to correct yet another triggering bug. On single capture trigger events, the scope had to be triggered twice to capture one waveform. Now every event is captured.
- Addition of user defined refresh rate.
- Implementation of all configuration file options.
- Addition of waveform and measurement logging. This adds data recorder capability to the oscilloscope program which could be helpful for capturing behavior like battery discharge curves or filter bode plots.
- PCB layout drawn in FreePCB and exported as Gerbers and PDF files.
- Modifications to hardware for future USB interface (now hardware version 1.2). Prior versions of the hardware are still supported in software and firmware updates.

Release Notes for version 2.131 build 2/1/2011

- Change to the firmware to correct yet another triggering bug. Thanks to Ger Van Den Hoek for his help in discovering and troubleshooting the bug.

Release Notes for version 2.13 build 11/18/2009

- Change to the firmware to correct a triggering bug. At slower trigger intervals, the software would attempt communication during a trigger event. The trigger event would cause the communication to be interrupted. Periodically, the interruption of communication would leave the communication lines in an invalid state and the oscilloscope would quit responding to further communications. This bug has been corrected in the firmware.
- Added auto measurements (auto peak to peak, rise time, fall time, period, frequency, signal rms, signal average, duty cycle, etc.).

Release Notes for version 2.12 build 4/1/2009

- Added Repetitive sampling, "time equivalent" modes for sampling waveforms up to a 5 MHz sample rate
- Expanded interlaced sampling mode to 417 kHz maximum sample rate
- Changed trigger functionality so that when the trigger is turned off, the scope reconfigures without a trigger event (before the scope would not update until a trigger occurred. This caused some confusion, because the user turned the trigger off and had to toggle the power on the oscilloscope or force a trigger event to see the screen update.
- Shortened minimum trigger delay to 2.6 us, improved trigger delay resolution, and extended maximum trigger delay
- Changed the panel incremental buttons to spinner buttons. This change adds keyboard arrow and mouse scroll wheel functionality to selecting the Time-per-Div, Volts-per-Div for each channel, Voltage Offset for each channel, and the Trigger Delay
- Program Menu enhancements, the addition of radio buttons and check boxes to indicate oscilloscope settings
- Other interface enhancements such as larger buttons for toolbar, changing of mouse cursors with "see thru hole" for better measurement on the scope screen
- Correction of bug that was causing the Time-per-Div reported by the scope panel to be slightly in error
- Correction of bug that was causing incorrect behavior when sampling at less than 9,000 Hz. The oscilloscope software was always assuming that data was recieved whenever requested. However, at the lower sampling rates, data wasn't aways ready to be reported to the PC
- Correction of bug that was causing the voltages to be scaled incorrectly by 23 percent
- Clarification on note for R24 on the Schematic
- Additional topics added to the help system
- Additional wiring diagram added to the PCB directory showing how components are connected to the PCB that are mounted on the front or back panels of the oscilloscope enclosure

#### Future Revisions

Here are my plans for future revisions of the hardware and software including:

- Computer interfacing on the USB port
- Hardware calibration (voltage per division)
- Extended math functions and math function graphing
- User selectable windowing functions (Rectangular [default - included in software now], Hanns, Hamming, Gauss, Blackman, etc)
- User interface enhancements, color choices, etc (fun stuff)
- Multi-language support

#### Support

I'd be glad to help with the installation of this software, the construction of the oscilloscope hardware, the understanding of the source code, the addition of functionality to the software, or the accepting of bug reports and the repairing of bugs. If you just need someone to e-mail every now and then, I don't mind making friends. I am not nearly as enthusiastic about doing your homework or helping on some unrelated project unless I find it interesting. That said, you can ask, but I don't give any promises about my expertise in anything except matters directly relating to the software and hardware schematics delivered here.

#### Files for download:

PPM Scope for Windows version 2.14
 | A DIY (do it yourself) oscilloscope with a maximum sample rate of 1 MHz and an equivalent maximum sample rate of 5 MHz.
| Filename | | Description | Size/Date
| PPMScopeWin.zip v.2.141 |  | Includes a description, source code, executable files, hex files, schematics, and PCB layout. | 4.29 MB - 4/4/2012
| PPMScopeDatasheets.zip |  | The component datasheets for the PPMScope. | 3.72 MB - 12/12/2011
| DaveDeBoer_Perfboard.zip |  | A perfboard layout with an integrated power supply on a 4"x6" board designed and contributed by Dave de Boer. | 2.97 MB - 1/10/2012
| Chris_PCB.zip |  | An alternative PCB layout optimized for easy etching on a single sided copper board. Designed and contributed by Krzysztof Passowicz. | 1.22 MB - 3/30/2012
| Online Help File | | Read the online help file for introduction, construction, and operation instructions.

##### Please see the terms and conditions before downloading.

##### If you would like to be notified when I update the project, please join the mailing list. Click here to send me comments or suggestions.

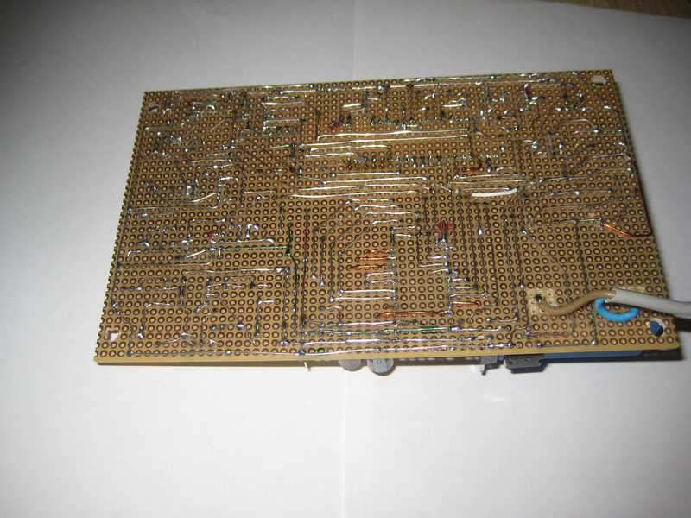
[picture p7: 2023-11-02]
Contributions/DaveDeBoer_Perfboard/Build_DavidDeBoer_bot.jpg

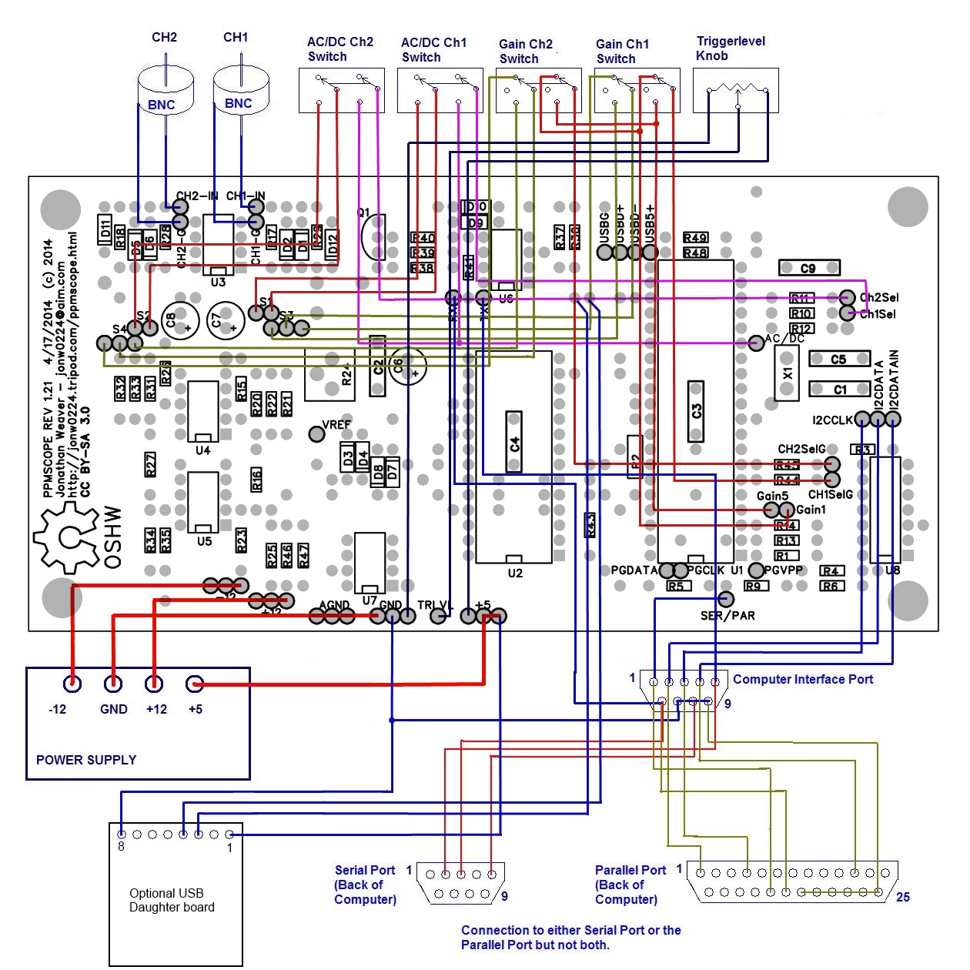
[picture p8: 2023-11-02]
PCsource/Help/WiringOfPCB.jpg

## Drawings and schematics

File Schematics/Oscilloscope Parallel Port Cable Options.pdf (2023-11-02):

# Option 1: Connections as described in Schematic (on page 4) using custom cable

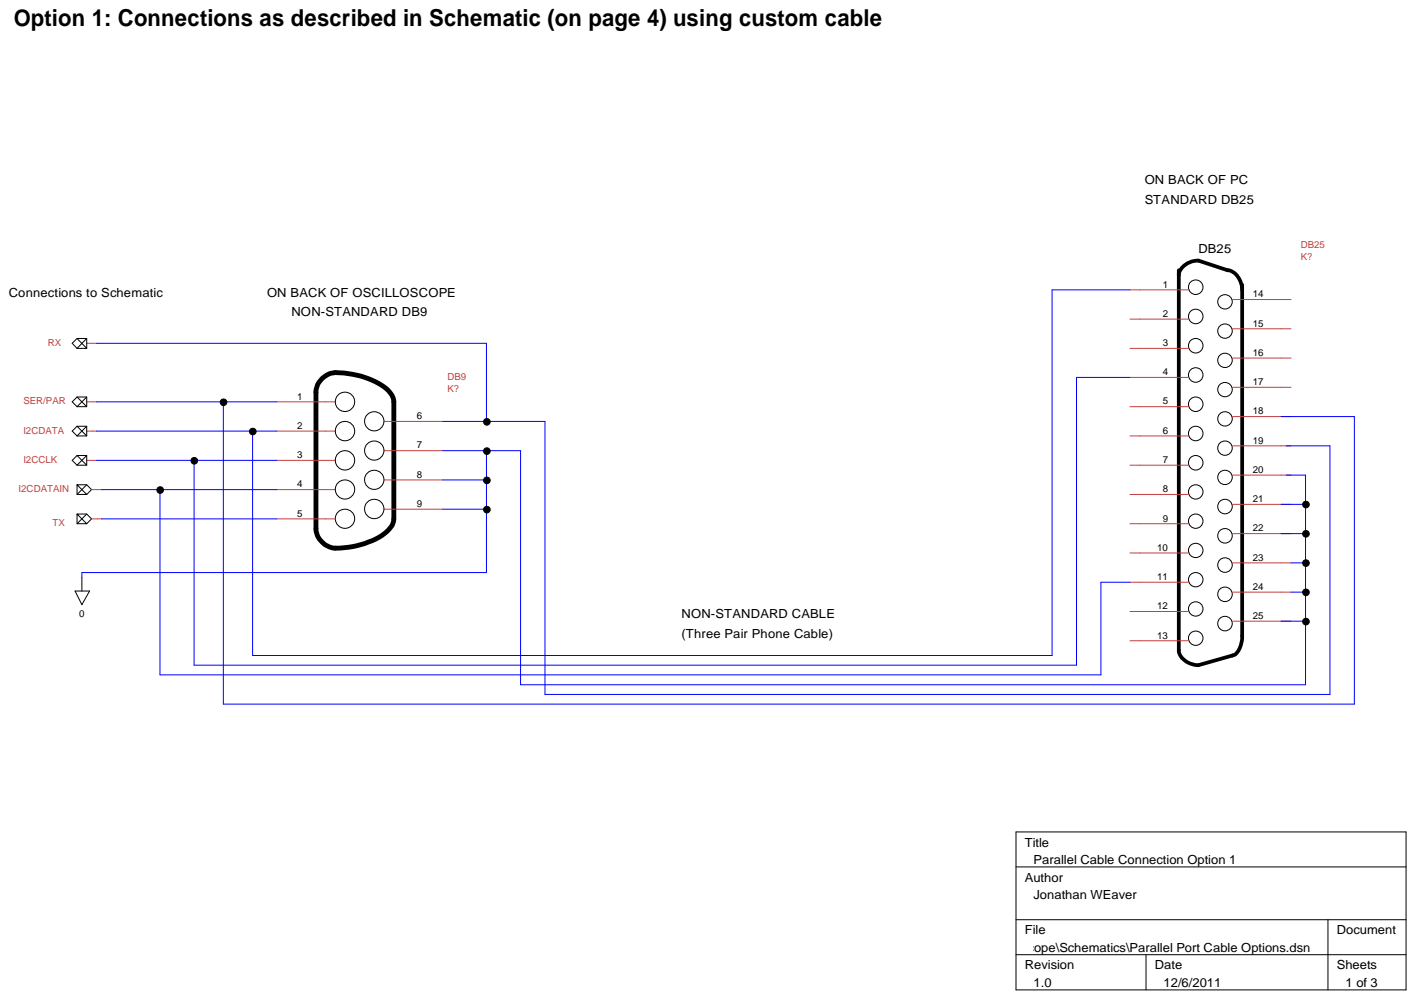
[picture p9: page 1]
SER/PAR; I2CDATA; I2CCLK; I2CDATAIN; NON-STANDARD CABLE

ON BACK OF PC
STANDARD DB25

Connections to Schematic

ON BACK OF OSCILLOSCOPE
NON-STANDARD DB9

(Three Pair Phone Cable)

Title
Parallel Cable Connection Option 1
Author
Jonathan WEaver

File | Document

E:\Projects\PPMScope\Schematics\Parallel Port Cable Options.dsn

Revision 1.0 | Date 12/6/2011 | Sheets 1 of 3

# Option 2: Standard Cable using DB25 on Oscilloscope

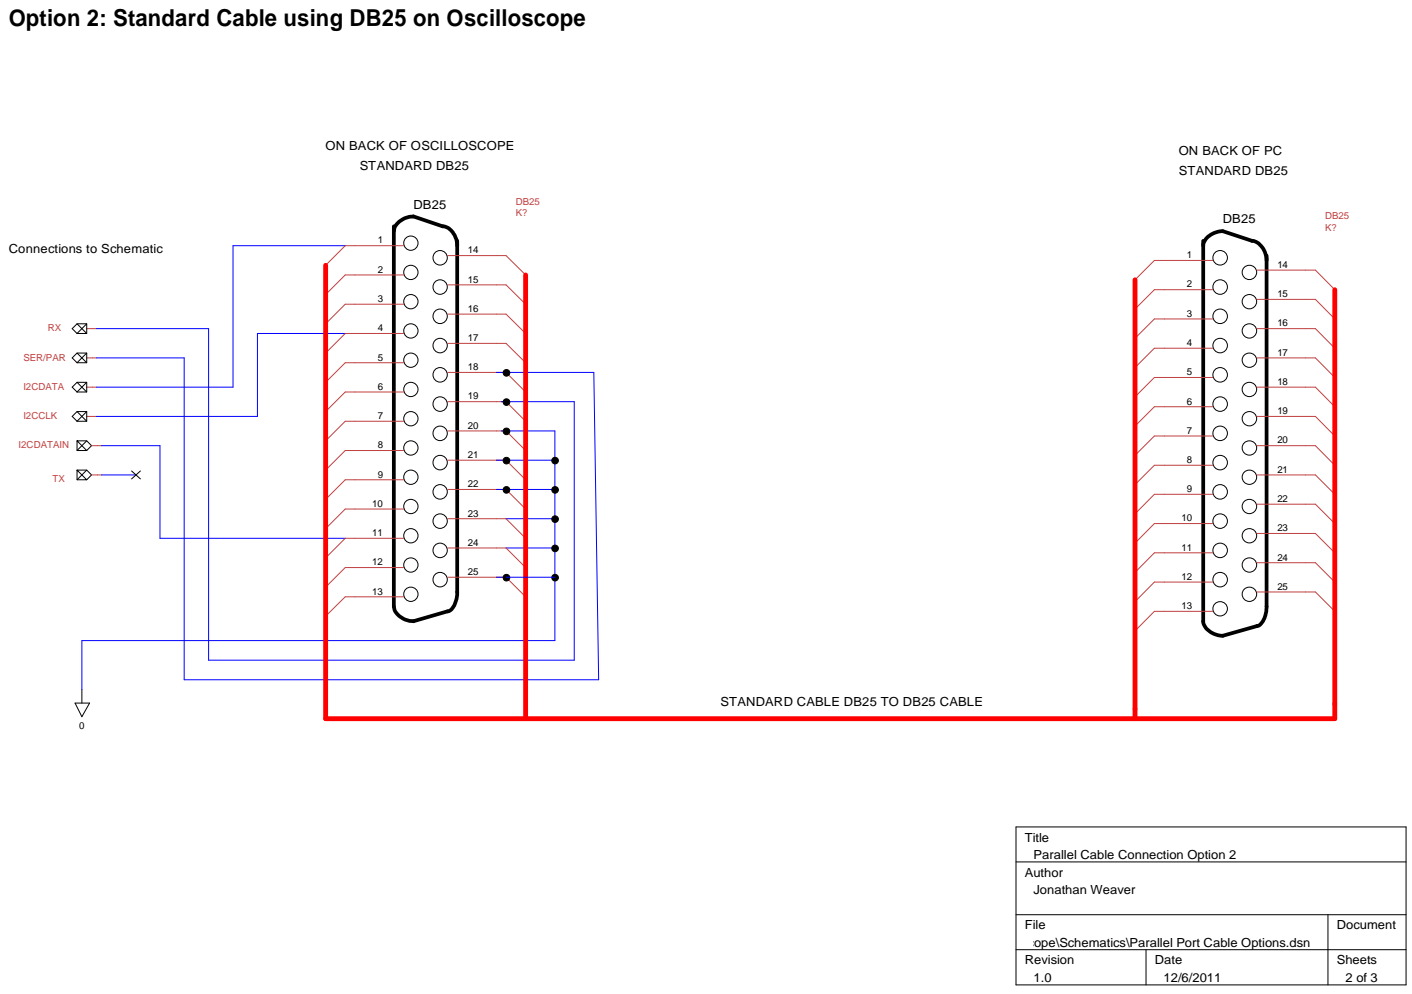
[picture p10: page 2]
SER/PAR; I2CDATA; I2CCLK; I2CDATAIN

ON BACK OF OSCILLOSCOPE
STANDARD DB25

ON BACK OF PC

Connections to Schematic

STANDARD CABLE DB25 TO DB25 CABLE

Title
Parallel Cable Connection Option 2
Author
Jonathan Weaver

File | Document

E:\Projects\PPMScope\Schematics\Parallel Port Cable Options.dsn

Revision 1.0 | Date 12/6/2011 | Sheets 2 of 3

Option 3: Custom Cable using Two Pair Phone Cable and DB9/DB25 Shields (Economical Option)

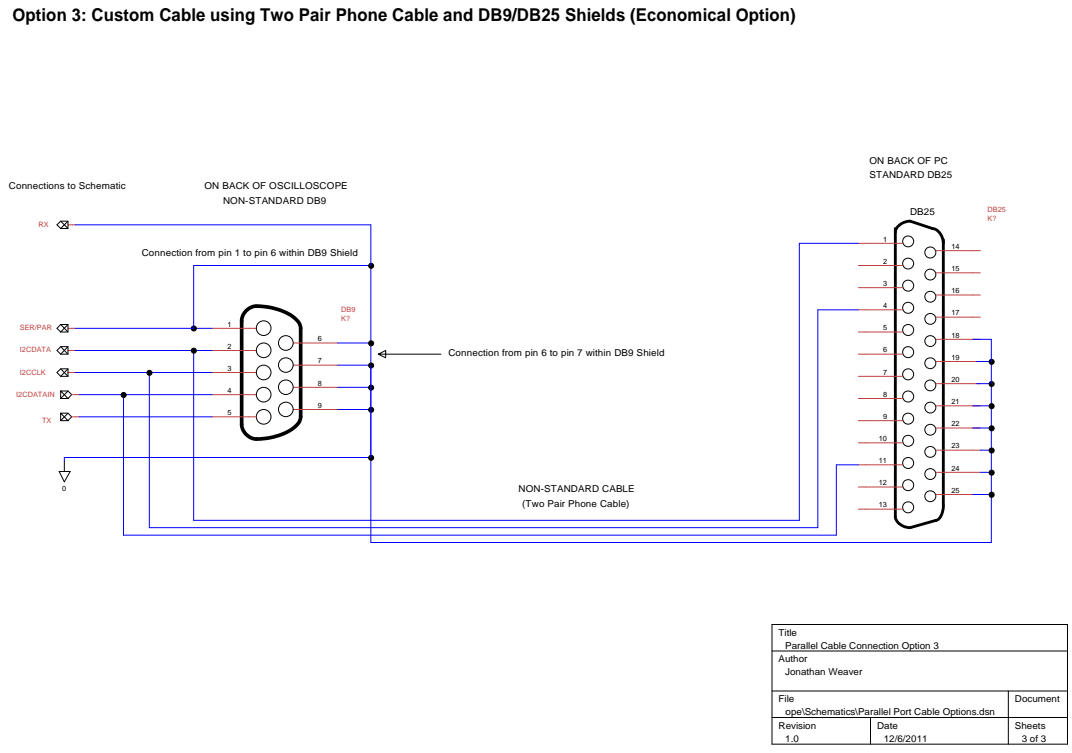
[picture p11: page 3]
SER/PAR; I2CDATA; I2CCLK; I2CDATAIN; NON-STANDARD CABLE

ON BACK OF PC
STANDARD DB25

Connections to Schematic

ON BACK OF OSCILLOSCOPE
NON-STANDARD DB9

Connection from pin 1 to pin 6 within DB9 Shield

Connection from pin 6 to pin 7 within DB9 Shield

(Two Pair Phone Cable)

Title
Parallel Cable Connection Option 3
Author
Jonathan Weaver

File | Document

E:\Projects\PPMScope\Schematics\Parallel Port Cable Options.dsn

Revision 1.0 | Date 12/6/2011 | Sheets 3 of 3

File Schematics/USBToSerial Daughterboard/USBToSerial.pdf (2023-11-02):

# Serial to USB Interface Board for Microcontroller UART

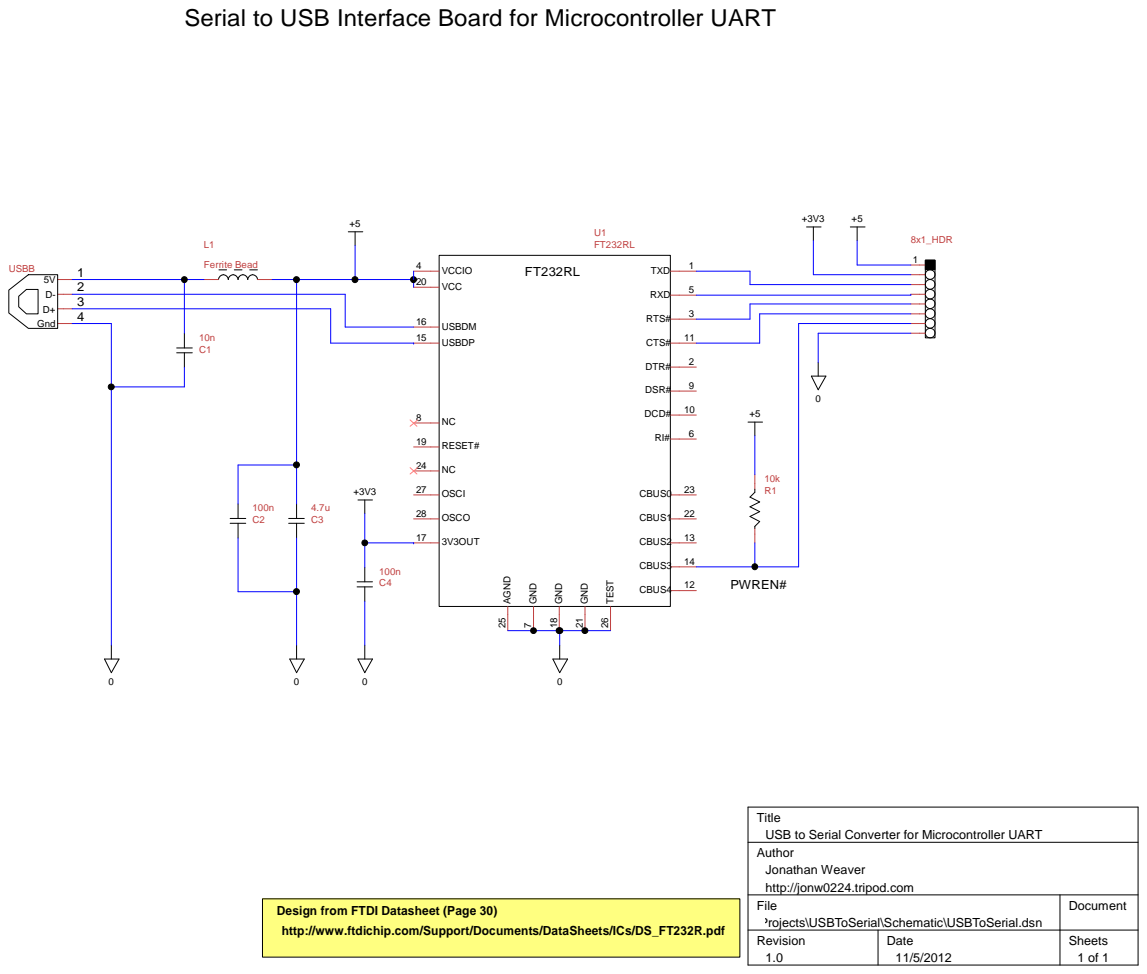
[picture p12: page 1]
TXD; DTR#; RTS#; VCCIO 4; RXD; GND; DSR#; DCD# 10; CTS# 11; CBUS4 12; CBUS2 13; CBUS3 14; USBDP 15; USBDM 16; 3V3OUT 17; RESET# 19; VCC 20; CBUS1 22; CBUS0 23; AGND; TEST; OSCI 27; OSCO 28; 5V D- D+ Gnd; USBB; Ferrite Bead; PWREN#; 8x1_HDR

Title
USB to Serial Converter for Microcontroller UART
Author
Jonathan Weaver
http://jonw0224.tripod.com

Design from FTDI Datasheet (Page 30)
http://www.ftdichip.com/Support/Documents/DataSheets/ICs/DS_FT232R.pdf

File | Document

C:\jww\Projects\USBToSerial\Schematic\USBToSerial.dsn

Revision 1.0 | Date 11/5/2012 | Sheets 1 of 1

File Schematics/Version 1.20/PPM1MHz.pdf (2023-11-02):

## Oscilloscope Overview

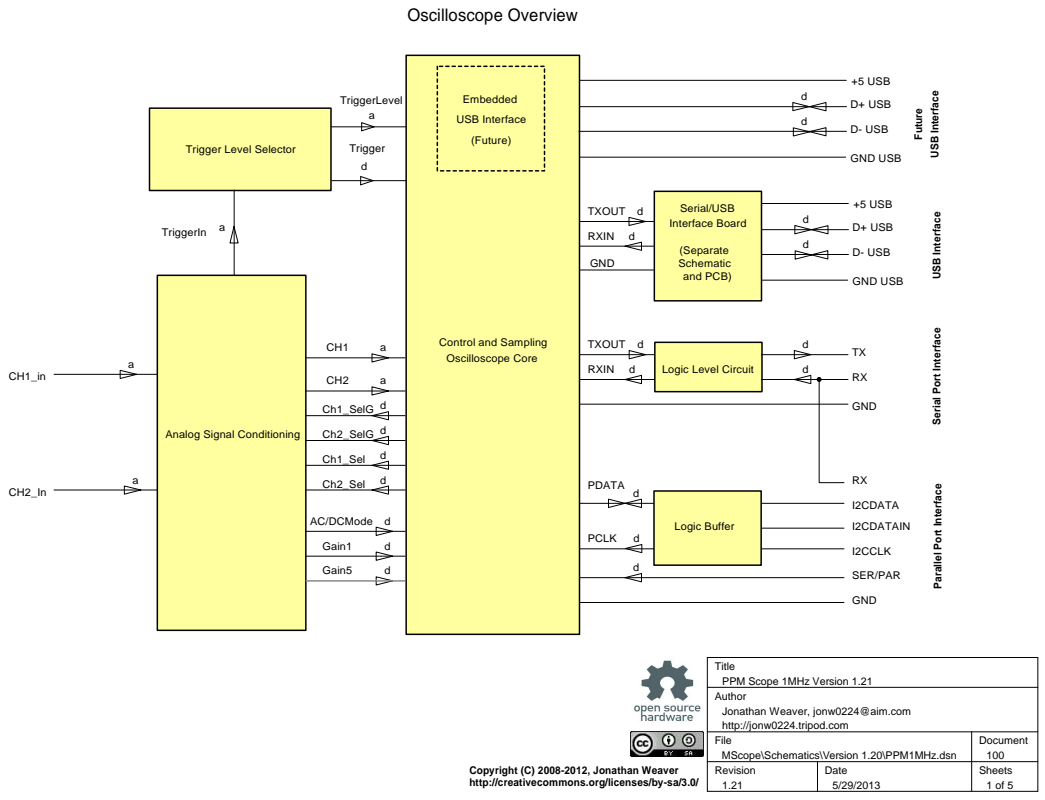
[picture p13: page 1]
I2CDATA; I2CDATAIN; I2CCLK; SER/PAR; GND; TXOUT; RXIN d; Trigger; TriggerLevel a; a TriggerIn; Ch1_Sel; Ch2_Sel; AC/DCMode; Gain1; Gain5; Ch1_SelG; Ch2_SelG; Logic Buffer; PDATA; PCLK; Serial/USB; D- USB; D+ USB; GND USB; Interface Board; (Separate Schematic and PCB); +5 USB; USB Interface; (Future); Embedded; Future

Trigger Level Selector

Serial Port Interface

Control and Sampling
Oscilloscope Core

Logic Level Circuit

Analog Signal Conditioning

Parallel Port Interface dd

Title
PPM Scope 1MHz Version 1.21
Author
Jonathan Weaver, jonw0224@aim.com
http://jonw0224.tripod.com

File | Document

C:\SkyDrive\Projects\PPMScope\Schematics\Version 1.20\PPM1MHz.dsn

Copyright (C) 2008-2012, Jonathan Weaver
http://creativecommons.org/licenses/by-sa/3.0/

Revision | Date 5/29/2013 | Sheets 1 of 5

## Control and Sampling - Oscilloscope Core

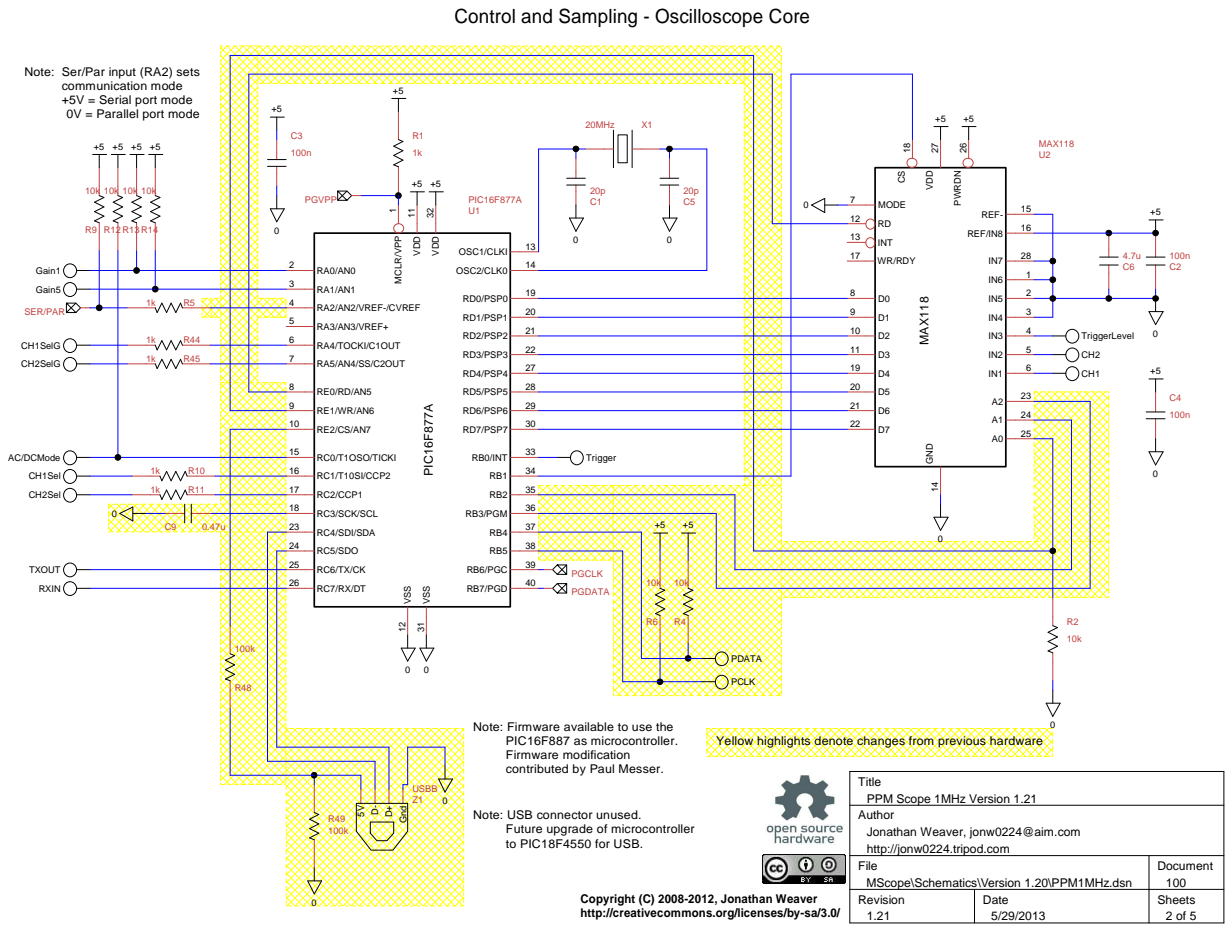
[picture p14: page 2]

Note: Ser/Par input (RA2) sets
communication mode
+5V = Serial port mode
0V = Parallel port mode

Note: Firmware available to use the
PIC16F887 as microcontroller.
Firmware modification
contributed by Paul Messer.

Yellow highlights denote changes from previous hardware

Title
PPM Scope 1MHz Version 1.21
Author
Jonathan Weaver, jonw0224@aim.com
http://jonw0224.tripod.com
File

USBB
Note: USB connector unused.
Future upgrade of microcontroller
to PIC18F4550 for USB.

## Analog Signal Conditioning

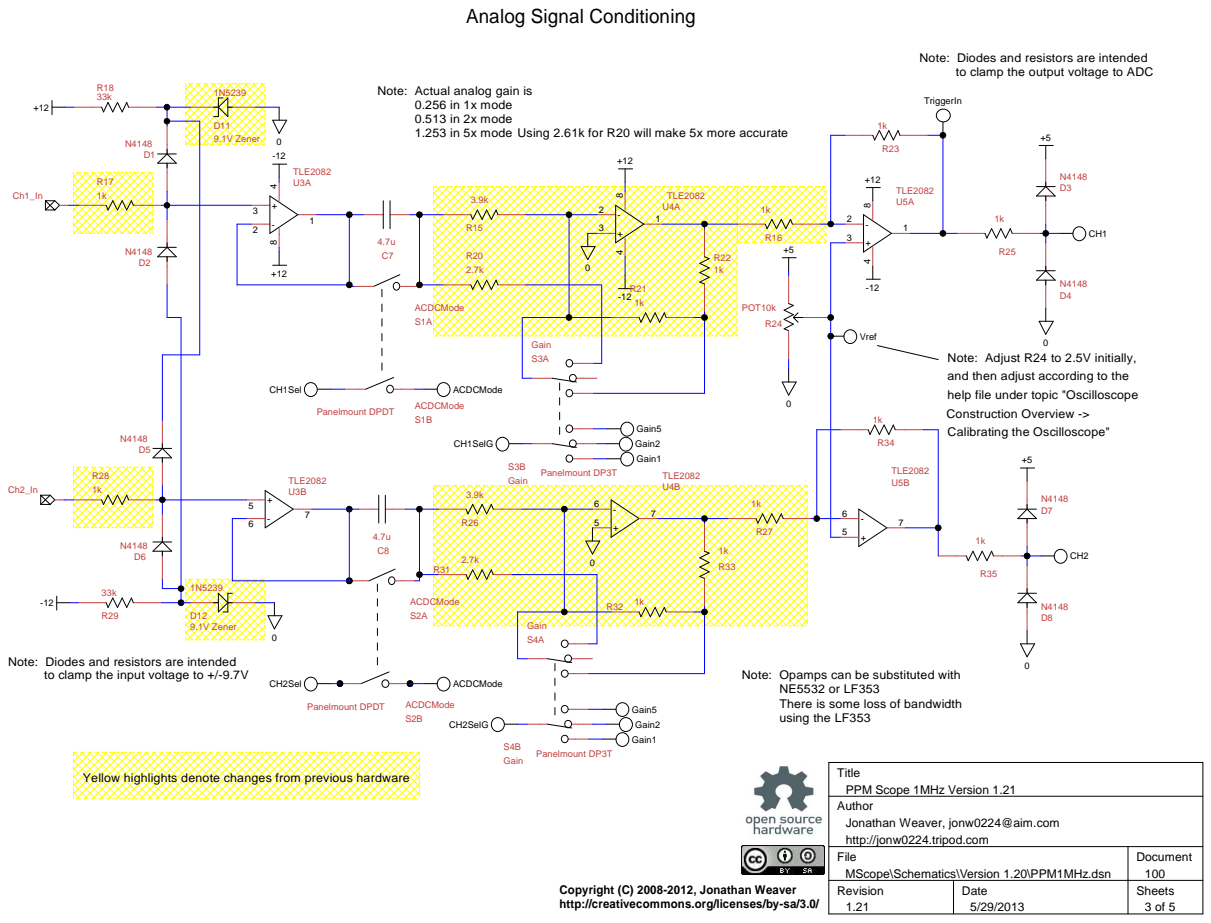
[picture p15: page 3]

Note: Diodes and resistors are intended
to clamp the output voltage to ADC

Note: Actual analog gain is
0.256 in 1x mode
0.513 in 2x mode
1.253 in 5x mode

Using 2.61k for R20 will make 5x more accurate

Note: Adjust R24 to 2.5V initially,
and then adjust according to the
help file under topic "Oscilloscope
Construction Overview ->
Calibrating the Oscilloscope"

to clamp the input voltage to +/-9.7V

Note: Opamps can be substituted with
There is some loss of bandwidth
using the LF353

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

Yellow highlights denote changes from previous hardware

## Serial Interface - Logic Level Circuits

## Parallel Port Interface - Logic Buffer

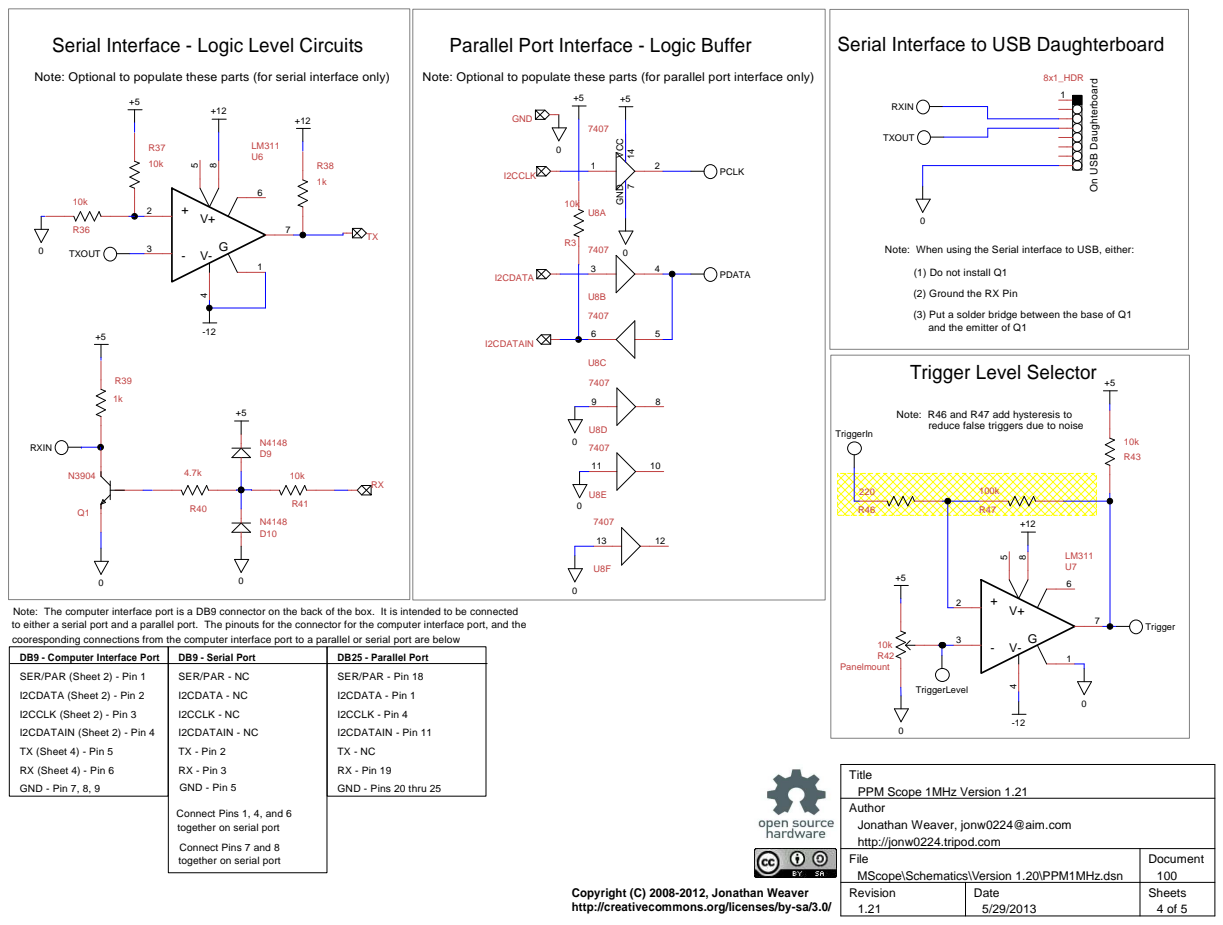
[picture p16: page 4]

Serial Interface to USB Daughterboard

Note: Optional to populate these parts (for serial interface only)

Note: Optional to populate these parts (for parallel port interface only)

Note: When using the Serial interface to USB, either:

(1) Do not install Q1
(2) Ground the RX Pin
(3) Put a solder bridge between the base of Q1
and the emitter of Q1
Trigger Level Selector

Note: R46 and R47 add hysteresis to
reduce false triggers due to noise

Note: The computer interface port is a DB9 connector on the back of the box. It is intended to be connected
to either a serial port and a parallel port. The pinouts for the connector for the computer interface port, and the
cooresponding connections from the computer interface port to a parallel or serial port are below
DB9 - Computer Interface Port
SER/PAR (Sheet 2) - Pin 1
I2CDATA (Sheet 2) - Pin 2
I2CCLK (Sheet 2) - Pin 3
I2CDATAIN (Sheet 2) - Pin 4
TX (Sheet 4) - Pin 5
RX (Sheet 4) - Pin 6
GND - Pin 7, 8, 9

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

Connect Pins 1, 4, and 6
together on serial port
Connect Pins 7 and 8

## Power Supply (Not on PCB)

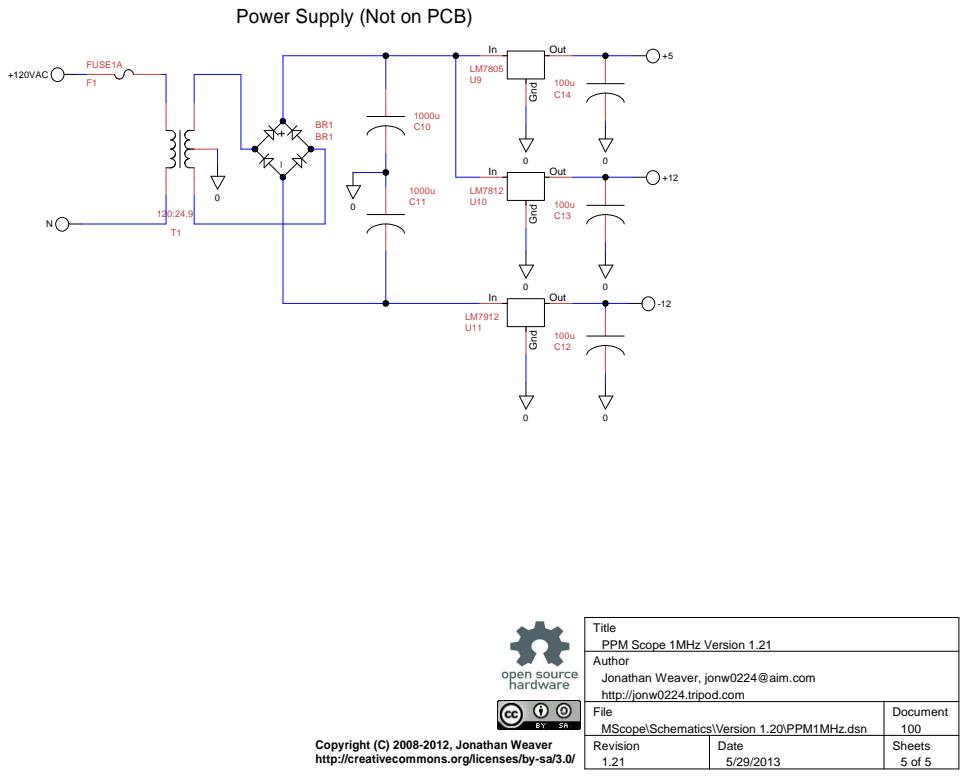
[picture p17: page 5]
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

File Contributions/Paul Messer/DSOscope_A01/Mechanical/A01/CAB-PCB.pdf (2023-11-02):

CH 1 | CH 2

4.000 in.

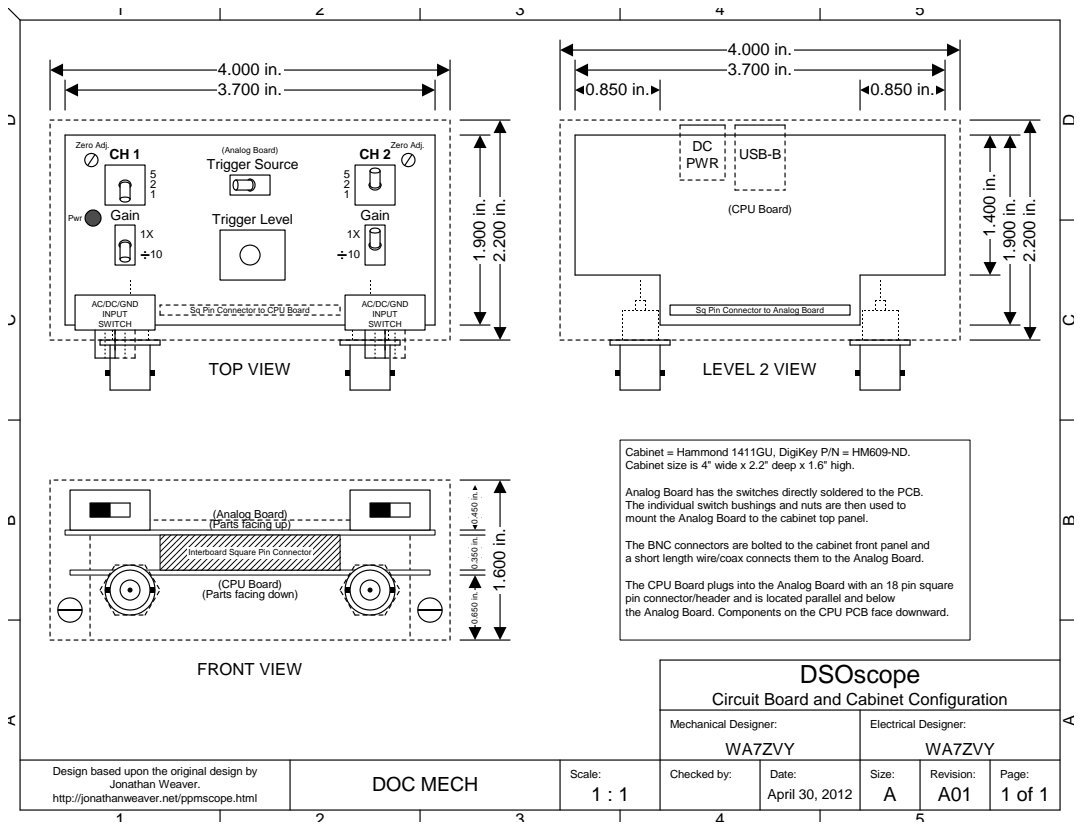
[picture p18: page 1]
Gain; Zero Adj.; Pwr; (Analog Board); DSOscope; Electrical Designer:; Trigger Source; Trigger Level; (CPU Board); USB-B; TOP VIEW; FRONT VIEW; LEVEL 2 VIEW; DC PWR

AC/DC/GND
INPUT
SWITCH

Sq Pin Connector to CPU Board

Sq Pin Connector to Analog Board

Cabinet = Hammond 1411GU, DigiKey P/N = HM609-ND.
Cabinet size is 4" wide x 2.2" deep x 1.6" high.

Analog Board has the switches directly soldered to the PCB.
The individual switch bushings and nuts are then used to
mount the Analog Board to the cabinet top panel.

(Analog Board)
(Parts facing up)

The BNC connectors are bolted to the cabinet front panel and
a short length wire/coax connects them to the Analog Board.

Interboard Square Pin Connector

(CPU Board)
(Parts facing down)

The CPU Board plugs into the Analog Board with an 18 pin square
pin connector/header and is located parallel and below
the Analog Board. Components on the CPU PCB face downward.

Circuit Board and Cabinet Configuration

Mechanical Designer: WA7ZVY | WA7ZVY

Design based upon the original design by Jonathan Weaver. http://jonathanweaver.net/ppmscope.html | | Checked by: | April 30, 2012 Date: | Size: A | Revision: A01 DOC MECH | Page: 1 of 1 Scale: 1 : 1

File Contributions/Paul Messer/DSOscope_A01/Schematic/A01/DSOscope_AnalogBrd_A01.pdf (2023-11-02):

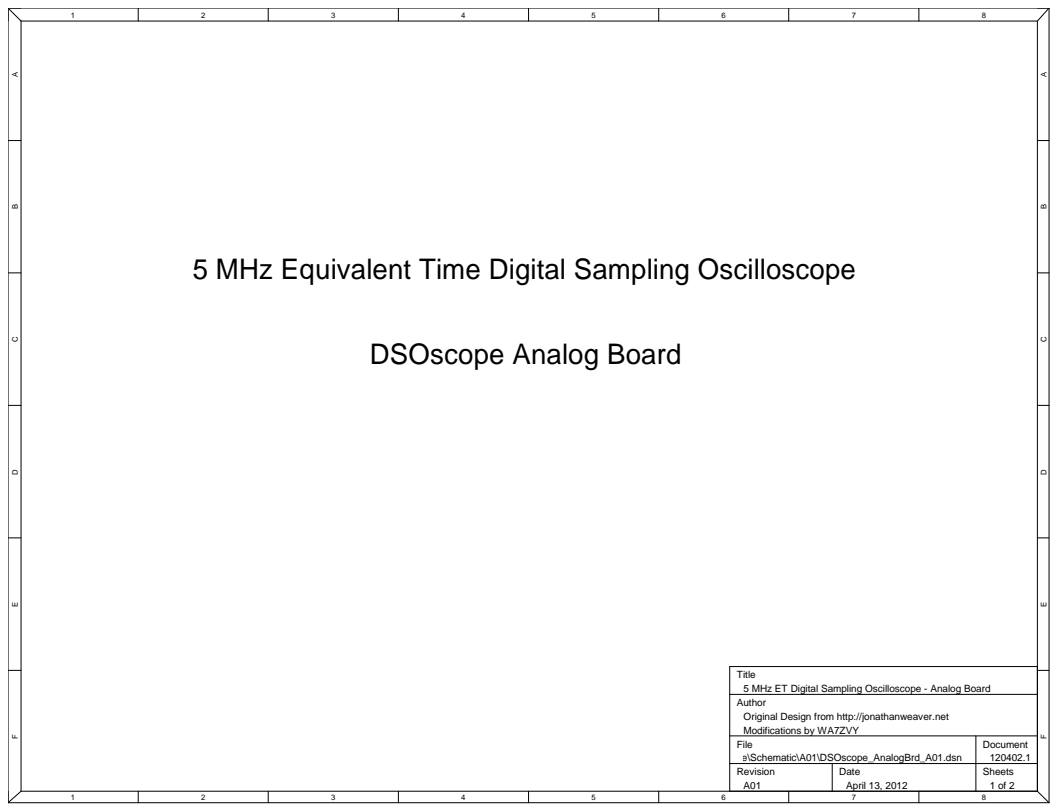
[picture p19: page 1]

5 MHz Equivalent Time Digital Sampling Oscilloscope

DSOscope Analog Board

Title
5 MHz ET Digital Sampling Oscilloscope - Analog Board
Author
Original Design from http://jonathanweaver.net
Modifications by WA7ZVY

File AnalogBrd_A01.dsn | Document 120402.1

Revision A01 | Date April 13, 2012 | Sheets 1 of 2

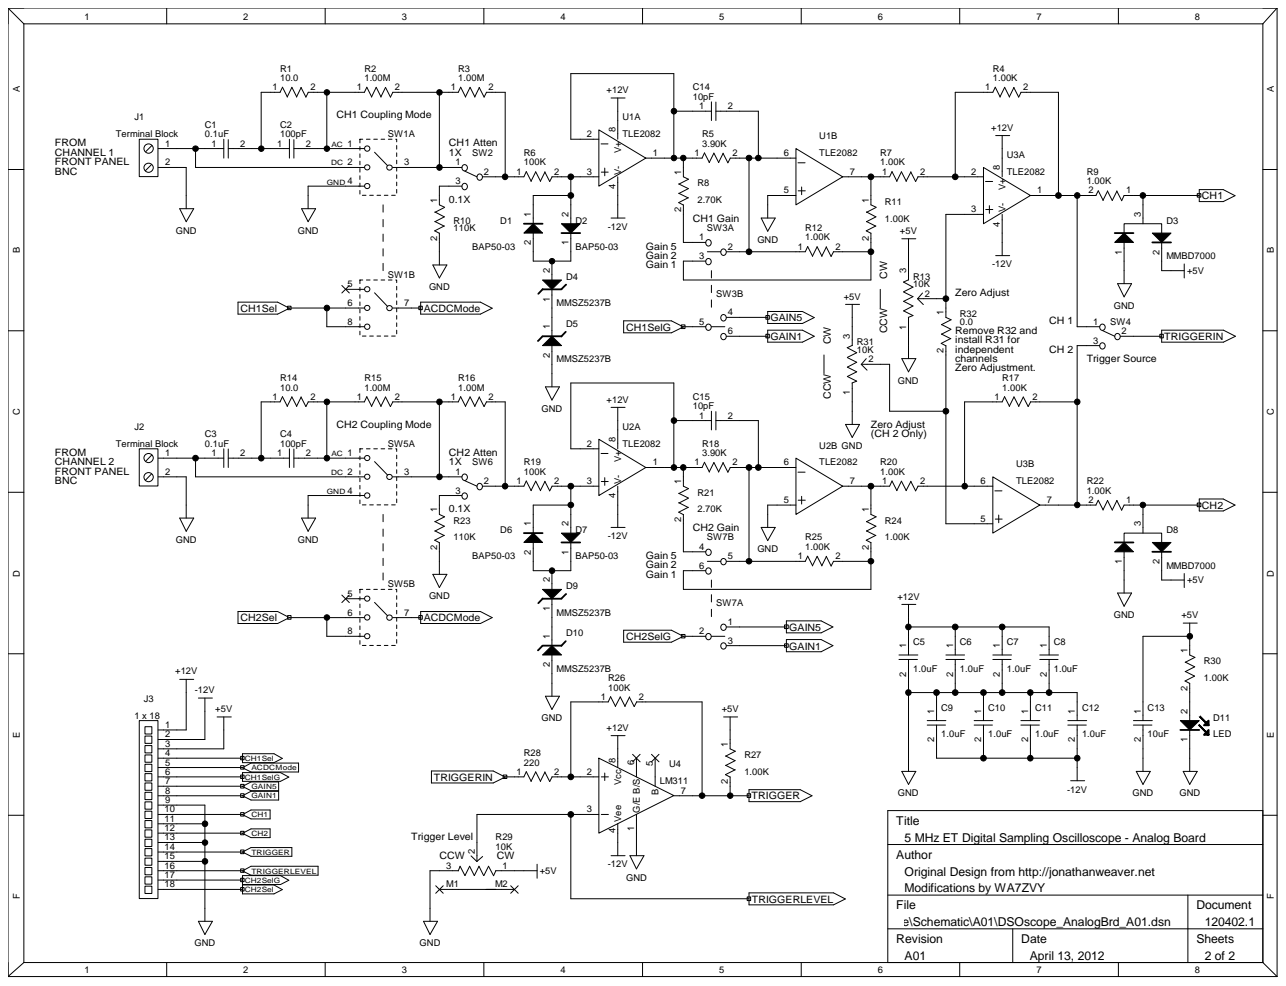
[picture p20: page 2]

Zero Adjust (CH 2 Only)

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

File AnalogBrd_A01.dsn | Document 120402.1

Revision A01 | Date April 13, 2012 | Sheets 2 of 2

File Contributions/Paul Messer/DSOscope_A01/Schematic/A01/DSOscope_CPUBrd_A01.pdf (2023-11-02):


5 MHz Equivalent Time Digital Sampling Oscilloscope

DSOscope CPU Board

Title
5 MHz ET Digital Sampling Oscilloscope - CPU Board
Author
Original Design from http://jonathanweaver.net
Modifications by WA7ZVY

File CPUBrd_A01.dsn | Document 120402.1

Revision A01 | Date April 13, 2012 | Sheets 1 of 4


+5V disconnect,
for in-circuit
programming power overload reduction,

5 MHz ET Digital Sampling Oscilloscope - CPU Board
Author
Original Design from http://jonathanweaver.net
Modifications by WA7ZVY
File

GND; USB-B; USB_DATA+; USB_DATA-; USB_VBUS; TXOUT; RXIN; BOM_1; Cabinet Aluminum 4.0"x2.2"x1.6"; BOM_2; Feet - Bumpons; BOM_3; BOM_4; BOM_5; Document; CPUBrd_A01.dsn

TO/FROM INTERIUM SERIAL TO USB CONVERTER

TO/FROM RS-232 LEVEL CONVERTER WITH A RS-232 EXTERNAL I/O CONNECTOR

REMOVE 0.0 OHM RESISTORS
WHEN USING INTERIUM USB
CONVERTER.

BOM_6
BNC Jack 50 Ohm Panel Mount

BOM_8
Card Guide - Custom

BOM_7

BOM_9

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


May overload USB source current rating.

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

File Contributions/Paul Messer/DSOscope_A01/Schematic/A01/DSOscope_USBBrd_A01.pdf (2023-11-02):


5 MHz Equivalent Time Digital Sampling Oscilloscope

DSOscope USB Converter Board

Title
5 MHz ET Digital Sampling Oscilloscope - USB Converter Board
Author
Original Design from http://jonathanweaver.net
Modifications by WA7ZVY

File USBBrd_A01.dsn | Document 120424.1

Revision A01 | Date April 24, 2012 | Sheets 1 of 2


+5V_FILTERED

GND

DCD:L
CTS:L

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

File USBBrd_A01.dsn | Document 120424.1

Revision A01 | Date April 24, 2012 | Sheets 2 of 2

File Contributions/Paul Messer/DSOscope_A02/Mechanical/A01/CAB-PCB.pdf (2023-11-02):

CH 1 | CH 2

4.000 in.

Gain; Zero Adj.; Pwr; (Analog Board); DSOscope; Electrical Designer:; Trigger Source; Trigger Level; (CPU Board); USB-B; TOP VIEW; FRONT VIEW; LEVEL 2 VIEW; DC PWR

AC/DC/GND
INPUT
SWITCH

Sq Pin Connector to CPU Board

Sq Pin Connector to Analog Board

Cabinet = Hammond 1411GU, DigiKey P/N = HM609-ND.
Cabinet size is 4" wide x 2.2" deep x 1.6" high.

Analog Board has the switches directly soldered to the PCB.
The individual switch bushings and nuts are then used to
mount the Analog Board to the cabinet top panel.

(Analog Board)
(Parts facing up)

The BNC connectors are bolted to the cabinet front panel and
a short length wire/coax connects them to the Analog Board.

Interboard Square Pin Connector

(CPU Board)
(Parts facing down)

The CPU Board plugs into the Analog Board with an 18 pin square
pin connector/header and is located parallel and below
the Analog Board. Components on the CPU PCB face downward.

Circuit Board and Cabinet Configuration

Mechanical Designer: WA7ZVY | WA7ZVY

Electrical design based upon the original design work of Jonathan Weaver. http://jonathanweaver.net/ppmscope.html | | Checked by: | May 30, 2012 Date: | Size: A | Revision: A01 DOC MECH | Page: 1 of 4 Scale: 1 : 1

4.000 in.

0.750 in.

DSOscope; Electrical Designer:

CABINET TOP - TOP

Circuit Board and Cabinet Configuration

Mechanical Designer: WA7ZVY | WA7ZVY

May 30, 2012 | A | A01 DOC MECH | Page: 2 of 4 Scale: 1 : 1

3.900 in.
2.000 in.

DSOscope; Electrical Designer:; 0.375" BNC D Punch 2X; (FRONT EDGE); (REAR EDGE)

Note: The LM7805 mounts
with a 4-40 x 0.375" screw
and 4 Hex nuts at this
location. Provides heatsinking.

CABINET BOTTOM - BOTTOM VIEW

CABINET BOTTOM - FRONT VIEW

CABINET BOTTOM - SIDE VIEW

Circuit Board and Cabinet Configuration

Mechanical Designer: WA7ZVY | WA7ZVY

CABINET BOTTOM - REAR VIEW

May 30, 2012 | A | A01 DOC MECH | Page: 3 of 4 Scale: 1 : 1

CH 1 | CH 2

3.700 in.

GAIN; Zero Adj.; POWER; DSOscope; Electrical Designer:; TRIGGER SOURCE; TRIGGER LEVEL; TOP LABEL; FRONT LABEL; AC-DC-GND; AC-DC-GND ¹MHz DIGITAL STORAGE OSCILLOSCOPE; REAR LABEL; USB; +12VDC; WA7ZVY REV A01 SN00001

Max 100V (PP + DC)
DSOscope

1MHz DIGITAL STORAGE OSCILLOSCOPE

Circuit Board and Cabinet Configuration

Mechanical Designer: WA7ZVY | WA7ZVY

May 30, 2012 | A | A01 DOC MECH | Page: 4 of 4 Scale: 1 : 1

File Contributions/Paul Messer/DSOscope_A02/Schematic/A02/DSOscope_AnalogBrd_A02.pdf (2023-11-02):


5 MHz Equivalent Time Digital Storage Oscilloscope

DSOscope Analog Board

Title
5 MHz ET Digital Storage Oscilloscope - Analog Board
Author
Original Design from http://jonathanweaver.net
Modifications by WA7ZVY

File AnalogBrd_A02.dsn | Document 120402.2

Revision A02 | Date June 8, 2012 | Sheets 1 of 2


Zero Adjust
(CH 1 and optionally CH 2)

1 2 R32 DNI
Install R32 (0 ohm) and remove R31
for single adjust of both channels
Zero Adjustment.

Zero Adjust (CH 2 Only)

-12V GND
Title
5 MHz ET Digital Storage Oscilloscope - Analog Board
Author
Original Design from http://jonathanweaver.net
Modifications by WA7ZVY

File AnalogBrd_A02.dsn | Document 120402.2

Revision A02 | Date June 8, 2012 | Sheets 2 of 2

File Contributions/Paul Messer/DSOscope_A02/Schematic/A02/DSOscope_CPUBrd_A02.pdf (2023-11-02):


5 MHz Equivalent Time Digital Storage Oscilloscope

DSOscope CPU Board

Title
5 MHz ET Digital Storage Oscilloscope - CPU Board
Author
Original Design from http://jonathanweaver.net
Modifications by WA7ZVY

File CPUBrd_A02.dsn | Document 120402.2

Revision A02 | Date June 12, 2012 | Sheets 1 of 4


+5V disconnect,
for in-circuit
programming power overload reduction,

Title
5 MHz ET Digital Storage Oscilloscope - CPU Board
Author
Original Design from http://jonathanweaver.net
Modifications by WA7ZVY
File

GND; USB-B; USB_DATA+; USB_DATA-; USB_VBUS; TXOUT; RXIN; BOM_1; Cabinet Aluminum 4.0"x2.2"x1.6"; BOM_2; Feet - Bumpons; BOM_3; BOM_4; BOM_5; R18 DNI; BOM_16; 4-40 HEX NUT; BOM_17; BOM_19; BOM_20; Document; CPUBrd_A02.dsn

TO/FROM INTERIUM USB TO SERIAL CONVERTER BOARD

TO/FROM RS-232 LEVEL CONVERTER WITH AN RS-232 EXTERNAL I/O CONNECTOR

INSTALL 0.0 OHM RESISTORS
AT LOCATIONS R17 AND R18
WHEN USING A PIC18F4550 AT
LOCATION U2, IF THE FIRMWARE
SUPPORTS USB MODE.
R17 DNI

THE ITEMS IN THIS COLUMN ARE USED
TO HEATSINK MOUNT U3, THE 7805 VOLTAGE
REGULATOR, TO THE BOTTOM PAN OF THE
CABINET.

BOM_10
Card Guide - Custom

BOM_15
4-40 x 0.625 PAN HEAD SCREW

BOM_11

BOM_12
Top Cabinet Label - Custom

U3 7805 REGULATOR TAB IN STACK HERE

BOM_13
Front Cabinet Label - Custom

BOM_18
No. 4 INTERNAL TOOTH LOCK WASHER

BOM_14
Rear Cabinet Label - Custom

BOM_6
BNC Jack 50 Ohm Panel Mount

BOM_7

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

CABINET BOTTOM PAN IN STACK HERE

THIS NUT APPLIED LAST FROM OUTSIDE
OF CABINET WHEN FULLY ASSEMBLED.
BOM_21
4-40 HEX NUT

BOM_8
RG174/U Cable - Cut to Length 4.5"

BOM_9

## !!! IMPORTANT !!!


Install 0.0 OHM R19 if USB Powered.

Note: USB Powered configuration unverified at this time.

May overload USB source current rating.

Do Not Install U3 and Install 0.0 OHM R20 if USB Powered.
R20 DNI

DO NOT INSTALL J6 IF
USB POWERED.

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

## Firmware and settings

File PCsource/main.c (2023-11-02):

/* ==============================================================================
 * Author:  Jonathan Weaver, jonw0224@aim.com
 * E-mail Contact: jonw0224@aim.com
 * Description:  Main program controller, event handler.
 * Version: 2.15
 * Date: 7/20/2012
 * Filename:  main.c, main.h
 *
 * Versions History:
 *      2.01 - 7/27/2006 - Created files
 *      2.01 - 8/6/2006 - Added about dialog
 *      2.01 - 2/11/2009 - Modifications to main menu
 *      2.12 - 3/31/2009 - Modifications for extended trigger
 *      2.14 - 4/30/2009 - Modifications for measurements
 *      2.14 - 1/31/2011 - Modifications to settings load and save
 *      2.14 - 3/15/2011 - Modifications for Equiv Sampling checkbox on panel
 *      2.15 - 6/13/2012 - Modifications for keyboard accelerators and removed
 *                         limitation on window instances
 *      2.15 - 6/15/2012 - More modifications for keyboard accelerators
 *      2.15 - 7/20/2012 - Modified for continous Time Per Division
 *
 * Copyright (C) 2006 - 2012 Jonathan Weaver
 *
 * This file is part of PPMScope.
 *
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
 * ==============================================================================
 */

#include "main.h"
#include "aboutdlg.h"
#include "hardwaredlg.h"
#include "hdwtestdlg.h"
#include "parallel.h"
#include "refreshratedlg.h"
#include "caldlg.h"
#include "logdlg.h"

#include <stdio.h>
#include <time.h>

/*  Declare Windows procedure  */
LRESULT CALLBACK WindowProcedure (HWND, UINT, WPARAM, LPARAM);

/*  Make the class name into a global variable  */
char szClassName[ ] = "PPMScopeMain";

/* Search for other applications of the same window type
 * used to ensure only one instance by the main windows procedure */
BOOL CALLBACK Searcher(HWND hWnd, LPARAM lParam)
{
    DWORD result;
    HWND *target;
    LRESULT ok = SendMessageTimeout(hWnd, AREUME, 0, 0,
                    SMTO_BLOCK | SMTO_ABORTIFHUNG,
                    200,
                    &result);
    if(ok == 0) return TRUE; // ignore this and continue
    if(result == AREUME)
    { /* found it */
        target = (HWND *)lParam;
        *target = hWnd;
        return FALSE; // stop search
    } /* found it */
    return TRUE; // continue search
} // Searcher

/* Main windows procedure, called when the program runs */
int WINAPI WinMain (HINSTANCE hThisInstance,
                    HINSTANCE hPrevInstance,
                    LPSTR lpszArgument,
                    int nFunsterStil)

{
    MSG messages;            /* Here messages to the application are saved */
    WNDCLASSEX wincl;        /* Data structure for the windowclass */

#ifdef SINGLEINSTANCE
    /* Ensure first instance */
    BOOL alreadyRunning;
    HANDLE hMutexOneInstance = CreateMutex( NULL, FALSE,
        "PPMSCOPE-088FA840-B10D-11D3-BC36-006067709674");
    alreadyRunning = (GetLastError() == ERROR_ALREADY_EXISTS ||
                      GetLastError() == ERROR_ACCESS_DENIED);
    // The call fails with ERROR_ACCESS_DENIED if the Mutex was
    // created in a different users session because of passing
    // NULL for the SECURITY_ATTRIBUTES on Mutex creation);

    if (alreadyRunning)
    { /* kill this */
	    HWND hOther = NULL;
        EnumWindows(Searcher, (LPARAM)&hOther);

        if (hOther != NULL)
        { /* pop up */
            SetForegroundWindow(hOther);
            if (IsIconic(hOther))
            { /* restore */
                ShowWindow(hOther, SW_RESTORE);
            } /* restore */
        } /* pop up */

        return FALSE; // terminates the creation
    } /* kill this */

#endif

    hInstance = hThisInstance;    /* Remember where we come from */

    /* The Window structure */
    wincl.hInstance = hThisInstance;
    wincl.lpszClassName = szClassName;
    wincl.lpfnWndProc = WindowProcedure;      /* This function is called by windows */
    wincl.style = CS_DBLCLKS;                 /* Catch double-clicks */
    wincl.cbSize = sizeof(WNDCLASSEX);

    /* Use default icon and mouse-pointer */
    wincl.hIcon = LoadIcon(hInstance, MAKEINTRESOURCE(APP_ICON));
    wincl.hIconSm = (HICON) LoadImage(hInstance, MAKEINTRESOURCE(APP_SM_ICON), IMAGE_ICON, 16, 16, 0);
    wincl.hCursor = LoadCursor(NULL, IDC_ARROW);
    wincl.lpszMenuName = "MAINMENU";
    wincl.cbClsExtra = 0;                      /* No extra bytes after the window class */
    wincl.cbWndExtra = 0;                      /* structure or the window instance */
    /* Use Windows's default color as the background of the window */
    wincl.hbrBackground = (HBRUSH)(COLOR_3DFACE+1);

    /* Register the window class, and if it fails quit the program */
    if (!RegisterClassEx (&wincl))
        return 0;

    HACCEL g_hAcc = LoadAccelerators(hThisInstance, MAKEINTRESOURCE(1));

    /* The class is registered, let's create the program*/
    g_hMainWindow = CreateWindowEx (
           0,                   /* Extended possibilites for variation */
           szClassName,         /* Classname */
           WINDOWTEXT,          /* Title Text */
           WS_OVERLAPPEDWINDOW, /* default window */
           CW_USEDEFAULT,       /* Windows decides the position */
           CW_USEDEFAULT,       /* where the window ends up on the screen */
           720,                 /* The programs width */
           540,                 /* and height in pixels */
           HWND_DESKTOP,        /* The window is a child-window to desktop */
           NULL,                /* Main Menu */
           hThisInstance,       /* Program Instance handler */
           NULL                 /* No Window Creation data */
           );

    MoveWindowToDefaultPos();

    /* Make the window visible on the screen */
    ShowWindow (g_hMainWindow, nFunsterStil);

    /* Run the message loop. It will run until GetMessage() returns 0 */
    while (GetMessage (&messages, NULL, 0, 0))
    {
        /* Process Keyboard Accelerators */
        if(!TranslateAccelerator(g_hMainWindow, g_hAcc, &messages))
        {
            /* Forward messages to hPanel dialog */
            if (g_hPanel == 0 || !IsDialogMessage(g_hPanel, &messages))
            {
                /* Translate virtual-key messages into character messages */
                TranslateMessage(&messages);
                /* Send message to WindowProcedure */
                DispatchMessage(&messages);
            }
        }
    }
    /* The program return-value is 0 - The value that PostQuitMessage() gave */
    return messages.wParam;
}

/* Compares two strings, ignoring case and ignoring the whitespace
 * char* a: a pointer to the first string to compare to the second
 * char* b: a pointer to the second string to compare to the first
 * returns 0 if the two strings are identical */
int strcmpiwp(char* a,char* b)
{
    while(*a && *b)
    {
        if(*a == ' ' || *a == '\t')   /* Ignore whitespace */
            *a++;
        if(*b == ' ' || *b == '\t')   /* Ignore whitespace */
            *b++;
        if(tolower(*a) != tolower(*b))
        {
            break;
        }
        *a++;
        *b++;
    }
    return *a || *b;
}

/* Loads the default window position and sets the main window position */
BOOL MoveWindowToDefaultPos()
{
     char* pt;
     int x, y, w, h;
     x = strtod(getConfigPar("WINDOWPOSITIONX"), &pt);
     y = strtod(getConfigPar("WINDOWPOSITIONY"), &pt);
     w = strtod(getConfigPar("WINDOWPOSITIONW"), &pt);
     h = strtod(getConfigPar("WINDOWPOSITIONH"), &pt);
     return MoveWindow(g_hMainWindow, x, y, w, h, TRUE);
}

/* Loads the settings file from the hard-drive
 * pszFileName: the file name of the settings to be loaded
 * returns: 1 if successful, 0 if unsuccessful */
BOOL LoadSettingsFile(LPSTR pszFileName)
{
    char* iniStr;
    char configure[8];
    int portType, portNo, tickCnt, i;
    char a[RECLENGTH];
    char* pt;

    clearConfig();
    if(readConfigFile(pszFileName))
    {

        MoveWindowToDefaultPos();

        iniStr = getConfigPar("PORTTYPE");
        if(*iniStr == 'P')
            portType = PARALLELPORT;
        else if(*iniStr == 'S')
            portType = SERIALPORT;
        else
            portType = USBPORT;
        portNo = strtod(getConfigPar("PORTNUMBER"), &pt);
        tickCnt = strtod(getConfigPar("TICKCOUNT"), &pt);
        configure[0] = strtod(getConfigPar("CONFIGLOC1"), &pt);
        configure[1] = strtod(getConfigPar("TRIGGERDELAY0"), &pt);
        configure[2] = strtod(getConfigPar("TRIGGERDELAY1"), &pt);
        configure[3] = strtod(getConfigPar("TRIGGERDELAY2"), &pt);
        configure[4] = strtod(getConfigPar("TRIGGERDELAY3"), &pt);
        configure[5] = strtod(getConfigPar("SAMPLERATE0"), &pt);
        configure[6] = strtod(getConfigPar("SAMPLERATE1"), &pt);
        configure[7] = strtod(getConfigPar("SAMPLERATE2"), &pt);

        iniStr = getConfigPar("HARDWAREMODEL");
        if(*iniStr == 'D')
            setHardwareModel(DSOSCOPE);
        else
            setHardwareModel(PPMSCOPE);

        scopeRefreshRate = strtod(getConfigPar("REFRESHRATE"), &pt);

        setPenWeight(CHANNELA, strtod(getConfigPar("WEIGHTA"), &pt));
        setPenWeight(CHANNELB, strtod(getConfigPar("WEIGHTB"), &pt));
        setPenWeight(CHANNELC, strtod(getConfigPar("WEIGHTC"), &pt));
        setPenWeight(CHANNELD, strtod(getConfigPar("WEIGHTD"), &pt));

        /* Set the port address */
        if(portNo == LPTCUSTOM)
            setPortAdr(portNo, strtol(getConfigPar("PORTADDRESS"), &pt, 16));

        iniStr = getConfigPar("SAMPLEMODE");
        if(iniStr[0] == 'R')
            dispmode = MODE_RUN;
        else if(iniStr[0] == 'S')
            dispmode = MODE_STOP | MODE_HOLD;
        else if(iniStr[0] == 'H')
            dispmode = MODE_HOLD | MODE_RUN;
        else
            dispmode = MODE_STOP;

        iniStr = getConfigPar("CHAENABLED");
        if(iniStr[0] == 'Y')
            dispmode = dispmode | MODE_CHAENABLED;
        iniStr = getConfigPar("CHBENABLED");
        if(iniStr[0] == 'Y')
            dispmode = dispmode | MODE_CHBENABLED;
        iniStr = getConfigPar("CHCENABLED");
        if(iniStr[0] == 'Y')
            dispmode = dispmode | MODE_CHCENABLED;
        iniStr = getConfigPar("CHDENABLED");
        if(iniStr[0] == 'Y')
            dispmode = dispmode | MODE_CHDENABLED;

        chAVoltDiv = strtod(getConfigPar("CHAVOLTPERDIV"), &pt);
        chBVoltDiv = strtod(getConfigPar("CHBVOLTPERDIV"), &pt);
        chCVoltDiv = strtod(getConfigPar("CHCVOLTPERDIV"), &pt);
        chDVoltDiv = strtod(getConfigPar("CHDVOLTPERDIV"), &pt);
        chAOffset = strtod(getConfigPar("CHAOFFSET"), &pt);
        chBOffset = strtod(getConfigPar("CHBOFFSET"), &pt);
        chCOffset = strtod(getConfigPar("CHCOFFSET"), &pt);
        chDOffset = strtod(getConfigPar("CHDOFFSET"), &pt);

        /* Channel Makeup */
        iniStr = getConfigPar("CHA");
        chAmakeup = 0;
        for(i = CB_CHOICE1; i<= CB_CHOICE10; i++)
        {
            LoadString(hInstance, i, a, RECLENGTH);
            if(strcmpiwp(iniStr,a) == 0)
            {
                chAmakeup = i - CB_CHOICE1;
                break;
            }
        }
        iniStr = getConfigPar("CHB");
        chBmakeup = 0;
        for(i = CB_CHOICE1; i<= CB_CHOICE10; i++)
        {
            LoadString(hInstance, i, a, RECLENGTH);
            if(strcmpiwp(iniStr,a) == 0)
            {
               chBmakeup = i - CB_CHOICE1;
               break;
            }
        }
        iniStr = getConfigPar("CHC");
        chCmakeup = 0;
        for(i = CB_CHOICE14; i<= CB_CHOICE23; i++)
        {
            LoadString(hInstance, i, a, RECLENGTH);
            if(strcmpiwp(iniStr,a) == 0)
            {
               chCmakeup = i - CB_CHOICE14;
               break;
            }
        }
        iniStr = getConfigPar("CHD");
        chDmakeup = 0;
        for(i = CB_CHOICE14; i<= CB_CHOICE23; i++)
        {
            LoadString(hInstance, i, a, RECLENGTH);
            if(strcmpiwp(iniStr,a) == 0)
            {
               chDmakeup = i - CB_CHOICE14;
               break;
            }
        }

        /* MeasurementLoadSettingsFiles */
        iniStr = getConfigPar("MEASURE1");
        measureFunct[0] = 0;
        for(i = MEASURE_CHOICE0; i <= MEASURE_CHOICE24; i++)
        {
            LoadString(hInstance, i, a, RECLENGTH);
            if(strcmpiwp(iniStr,a) == 0)
            {
               measureFunct[0] = (i - MEASURE_CHOICE0) * 4;
               break;
            }
        }
        iniStr = getConfigPar("MEASURESOURCE1");
        for(i = MEASURE_SRC_CH1; i <= MEASURE_SRC_CH4; i++)
        {
            LoadString(hInstance, i, a, RECLENGTH);
            if(strcmpiwp(iniStr,a) == 0)
            {
                measureFunct[0]+= (i - MEASURE_SRC_CH1);
                break;
            }
        }
        iniStr = getConfigPar("MEASURE2");
        measureFunct[1] = 0;
        for(i = MEASURE_CHOICE0; i <= MEASURE_CHOICE24; i++)
        {
            LoadString(hInstance, i, a, RECLENGTH);
            if(strcmpiwp(iniStr,a) == 0)
            {
               measureFunct[1] = (i - MEASURE_CHOICE0) * 4;
               break;
            }
        }
        iniStr = getConfigPar("MEASURESOURCE2");
        for(i = MEASURE_SRC_CH1; i <= MEASURE_SRC_CH4; i++)
        {
            LoadString(hInstance, i, a, RECLENGTH);
            if(strcmpiwp(iniStr,a) == 0)
            {
                measureFunct[1]+= (i - MEASURE_SRC_CH1);
                break;
            }
        }
        iniStr = getConfigPar("MEASURE3");
        measureFunct[2] = 0;
        for(i = MEASURE_CHOICE0; i <= MEASURE_CHOICE24; i++)
        {
            LoadString(hInstance, i, a, RECLENGTH);
            if(strcmpiwp(iniStr,a) == 0)
            {
               measureFunct[2] = (i - MEASURE_CHOICE0)*4;
               break;
            }
        }
        iniStr = getConfigPar("MEASURESOURCE3");
        for(i = MEASURE_SRC_CH1; i <= MEASURE_SRC_CH4; i++)
        {
            LoadString(hInstance, i, a, RECLENGTH);
            if(strcmpiwp(iniStr,a) == 0)
            {
                measureFunct[2]+= (i - MEASURE_SRC_CH1);
                break;
            }
        }
        iniStr = getConfigPar("MEASURE4");
        measureFunct[3] = 0;
        for(i = MEASURE_CHOICE0; i <= MEASURE_CHOICE24; i++)
        {
            LoadString(hInstance, i, a, RECLENGTH);
            if(strcmpiwp(iniStr,a) == 0)
            {
               measureFunct[3] = (i - MEASURE_CHOICE0)*4;
               break;
            }
        }
        iniStr = getConfigPar("MEASURESOURCE4");
        for(i = MEASURE_SRC_CH1; i <= MEASURE_SRC_CH4; i++)
        {
            LoadString(hInstance, i, a, RECLENGTH);
            if(strcmpiwp(iniStr,a) == 0)
            {
                measureFunct[3]+= (i - MEASURE_SRC_CH1);
                break;
            }
        }

        iniStr = getConfigPar("RECONSTRUCTION");
        if(iniStr[0] == 'S')
            if(iniStr[1] == 'q')
                reconst = RECONST_SQUARE;
            else if(iniStr[1] == 'p')
                reconst = RECONST_BEZIER;
            else
                reconst = RECONST_SINC;
        else if(iniStr[0] == 'P')
            reconst = RECONST_POINT;
        else
            reconst = RECONST_TRIANGLE;

        iniStr = getConfigPar("ALLOWTIMEEQUIV");
        if(iniStr[0] == 'Y')
            setRepetitive(1);
        else
            setRepetitive(0);

        /* High resolution mode */
        iniStr = getConfigPar("HIGHRESMODE");
        if(iniStr[0] == 'Y')
            setHighResolution(1);
        else
            setHighResolution(0);

        setSamplesPerChannel(strtod(getConfigPar("BUFFERSIZE"), &pt));
        setOscDispType(g_hScreenMain, "SCREENATYPE");
        setOscDispType(g_hScreenA, "SCREENBTYPE");
        setOscDispType(g_hScreenB, "SCREENCTYPE");

        /* Colors */
        oscSetColors(strtol(getConfigPar("SCRBGCOLOR"), &pt, 16),
            strtol(getConfigPar("SCRFGCOLOR"), &pt, 16),
            strtol(getConfigPar("CHACOLOR"), &pt, 16),
            strtol(getConfigPar("CHBCOLOR"), &pt, 16),
            strtol(getConfigPar("CHCCOLOR"), &pt, 16),
            strtol(getConfigPar("CHDCOLOR"), &pt, 16),
            strtol(getConfigPar("CUR1COLOR"), &pt, 16),
            strtol(getConfigPar("CUR2COLOR"), &pt, 16),
            strtol(getConfigPar("TRIGGERCOLOR"), &pt, 16));

        hDriverSetConfig(portType, portNo, tickCnt, configure, BUFFER_MAX);

        /* Time Per Division */
        setTimePerDivision(strtod(getConfigPar("TIMEPERDIV"), &pt));

        /* Persistence */
        oscSetPersistence(strtod(getConfigPar("PERSISTENCE"), &pt));

        /* Update */
        SendMessage(g_hPanel, WM_REFRESHPANEL, 0, 0);
        MainWindowRefresh(g_hMainWindow);
        refreshScopeWindows(1);

        return 1;
    }
    else
    {
        portType = PARALLELPORT;
        portNo = 0;
        tickCnt = 500;
        configure[0] = 1 << 5;
        configure[1] = 0;
        configure[2] = 0;
        configure[3] = 0;
        configure[4] = 1;
        configure[5] = 0;
        configure[6] = 0;
        configure[7] = 1;

        hDriverSetConfig(portType, portNo, tickCnt, configure, BUFFER_MAX);
        hDriverInitialize();           /* Initialize hardware */
        SetTimer(g_hMainWindow, 1, scopeRefreshRate, NULL); /* Start redraw timer */
        currentChannel = 0;

        chAmakeup = CH1ONLY;
        chBmakeup = CH2ONLY;
        chCmakeup = CH1ONLY;
        chDmakeup = CH2ONLY;

        reconst = RECONST_TRIANGLE;
        dispmode = MODE_HOLD | MODE_STOP | MODE_CHAENABLED | MODE_CHBENABLED;

        chAVoltDiv = 5;
        chBVoltDiv = 5;
        chCVoltDiv = 5;
        chDVoltDiv = 5;
        chAOffset = 0;
        chBOffset = 0;
        chCOffset = 0;
        chDOffset = 0;

        SendMessage(g_hPanel, WM_REFRESHPANEL, 0, 0);
        MainWindowRefresh(g_hMainWindow);
        return 0;
    }
}
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

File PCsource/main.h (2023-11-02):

/* ==============================================================================
 * Author:  Jonathan Weaver, jonw0224@aim.com
 * E-mail Contact: jonw0224@aim.com
 * Description:  Main program controller, event handler.
 * Version: 2.15
 * Date: 7/20/2012
 * Filename:  main.c, main.h
 *
 * Versions History:
 *      2.01 - 7/27/2006 - Created files
 *      2.01 - 8/6/2006 - Added about dialog
 *      2.01 - 2/11/2009 - Modified for Panel changes, using Updown controls
 *                         and windows themes.
 *      2.14 - 4/30/2009 - Changed for measurements
 *      2.14 - 1/31/2011 - Modifications for colors
 *      2.15 - 7/20/2012 - Modified for continous Time Per Division
 *      2.19 - 3/10/2014 - Modified to handle panelwidth for any screen dpi setting.
 *
 * Copyright (C) 2006 - 2012 Jonathan Weaver
 *
 * This file is part of PPMScope.
 *
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
 * ==============================================================================
 */


#define WINVER 0x0500
#define _WIN32_IE 0x0500

#include <windows.h>
#include <commctrl.h>
#include "hdriver.h"
#include "oscdisp.h"
#include "panel.h"
#include "fourier.h"
#include "ini_io.h"
#include "func.h"
#include "settings.h"

/* Application Commands */
/* Menu items */
#define CM_FILE_SAVEWAVE                    9001
#define CM_FILE_SAVESET                     9002
#define CM_FILE_OPENSET                     9003
#define CM_FILE_LOGSETTINGS                 9004
#define CM_FILE_EXIT	                    9005
#define CM_CONFIG_HARDWARE                  9011
#define CM_CONFIG_HARDTEST                  9012
#define CM_CONFIG_CALIBRATE                 9013
#define CM_CONFIG_SAMPLE_INTERLACED         9014
#define CM_CONFIG_SAMPLE_TIMEEQUIV          9015
#define CM_CONFIG_TRIGGER_POS               9016
#define CM_CONFIG_TRIGGER_NEG               9017
#define CM_CONFIG_TRIGGER_OFF               9018
#define CM_CONFIG_WAVEFORM_REFRESH_RATE     9019
#define CM_WAVEFORM_RECON_SPLINE            9020
#define CM_WAVEFORM_RECON_TRI               9021
#define CM_WAVEFORM_RECON_SQU               9022
#define CM_WAVEFORM_RECON_PT                9023
#define CM_WAVEFORM_RECON_SINC              9024
#define CM_WAVEFORM_VT                      9025
#define CM_WAVEFORM_XY                      9026
#define CM_WAVEFORM_LIN                     9027
#define CM_WAVEFORM_LOG                     9028
#define CM_HELP_HELP                        9031
#define CM_HELP_ABOUT                       9032
#define CM_WAVEFORM_HIGH_RES                  9033

/* Toolbar buttons */
#define CM_SAVEWAVEFORM     CM_FILE_SAVEWAVE
#define CM_SAVESETUP        CM_FILE_SAVESET
#define CM_OPENSETUP        CM_FILE_OPENSET
#define CM_LOGGING          CM_FILE_LOGSETTINGS
#define CM_MODE_RUN         9101
#define CM_MODE_SINGLE      9102
#define CM_MODE_HOLD        9103
#define CM_RECON_SPLINE     CM_WAVEFORM_RECON_SPLINE
#define CM_RECON_TRI        CM_WAVEFORM_RECON_TRI
#define CM_RECON_SQU        CM_WAVEFORM_RECON_SQU
#define CM_RECON_PNT        CM_WAVEFORM_RECON_PT
#define CM_RECON_SIN        CM_WAVEFORM_RECON_SINC
#define CM_VIEW_VT          CM_WAVEFORM_VT
#define CM_VIEW_XY          CM_WAVEFORM_XY
#define CM_VIEW_LIN         CM_WAVEFORM_LIN
#define CM_VIEW_LOG         CM_WAVEFORM_LOG
#define CM_TRIG_POS         CM_CONFIG_TRIGGER_POS
#define CM_TRIG_NEG         CM_CONFIG_TRIGGER_NEG
#define CM_TRIG_OFF         CM_CONFIG_TRIGGER_OFF

//Range of toolbar commands
#define TB_CM_MIN           CM_FILE_SAVEWAVE
#define TB_CM_MAX           CM_MODE_HOLD

//Offset for tooltips
#define TOOLTIP_OFFSET      1000

//Offset for status bar descriptions
#define STATUS_OFFSET       2000
#define STATUSMSGBIN        1
#define STATUS_CONNECTED        2500
#define STATUS_NOT_CONNECTED    2501

//Default settings file
#define DEFAULTSETTINGS         2502

//Icons
#define APP_SM_ICON     2
#define APP_ICON        1
#define REDDOT          3
#define GREDOT          4

//Toolbar image properties
//Number
#define TBBUTTONNUM     24  // 19 images and 5 separators
#define TBSEPARATORS    5
#define TBIMGNUM        20  // One alternative image
#define TBLOGON         19  //Beginning of alternative image
#define TBLOGOFF        3

//size
#define TBIMGX          20
#define TBIMGY          20
//transparent color
#define TBTRANSCOLOR    RGB(192,192,192)
//bitmaps
#define SAVEBMP         10
#define SAVESETBMP      11
#define OPENSETBMP      12
#define MODE_RUNBMP     13
#define MODE_SINGLEBMP  14
#define MODE_HOLDBMP    15
#define RECON_TRIBMP    16
#define RECON_SQUBMP    17
#define RECON_PNTBMP    18
#define RECON_SINBMP    19
#define VIEW_VTBMP      20
#define VIEW_XYBMP      21
#define VIEW_LINBMP     22
#define VIEW_LOGBMP     23
#define TRIG_POSBMP     24
#define TRIG_NEGBMP     25
#define TRIG_OFFBMP     26
#define LOG_OFFBMP      27
#define LOG_ONBMP       28
#define RECON_SPLINEBMP 29

#define ID_STATUSBAR        4997
#define ID_TOOLBAR          4998

/* Dialog boxes */
#define DLG_STATIC          -1
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

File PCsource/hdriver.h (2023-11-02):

/* ==============================================================================
 * Author:  Jonathan Weaver, jonw0224@aim.com
 * E-mail Contact: jonw0224@aim.com
 * Description:  Hardware interface to the oscilloscope
 * Version: 2.18
 * Date: 1/17/2014
 * Filename:  hdriver.c, hdriver.h
 *
 * Versions History:
 *      9/6/2006 - Created file, configuration routines and background routines
 *      1/30/2013 - updated headers for hDriverSetConfig, hDriverGetConfig,
 *                  updateChannels
 *      1/17/2014 - Modified code for trigger levels to be reported on both
 *                  channels.  Changed definition of getTriggerLevel
 *
 * Copyright (C) 2006-2014 Jonathan Weaver
 *
 * This file is part of PPMScope.
 *
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
 * ==============================================================================
 */

#define BUFFER_MAX (256)

#define PARALLELPORT 1
#define SERIALPORT 2
#define USBPORT 3

/* Hardware Models */
#define PPMSCOPE    0
#define DSOSCOPE    1

/* Adjustments */
#define ADJ_NOADJ 0
#define ADJ_CINCR 1
#define ADJ_FINCR 2
#define ADJ_CDECR 3
#define ADJ_FDECR 4

/* Sample rates */
#define SAMPLE_1M           0
#define SAMPLE_833K         1
#define SAMPLE_625K         2
#define SAMPLE_417K         3
#define SAMPLE_250K         4
#define SAMPLE_DELAY        5
#define SAMPLE_REP5M        6
#define SAMPLE_REP2M        7
#define SAMPLE_XY417K       8
#define SAMPLE_XY250K       9
#define SAMPLE_XY192K       10
#define SAMPLE_XYDELAY      11
#define SAMPLE_XYINTDELAY   12
#define SAMPLE_XY500K       13

/* Diagnostic String for use by the hardware testing feature */
#define DIAGNOSTIC_UPPERBOUND 10000
char diagnostic[DIAGNOSTIC_UPPERBOUND];
/* Pointer for the end of the diagnostic string */
char *dPtr;
/* Macro definition for diagnostic printing */
#define DIAGPRINT if(dPtr<diagnostic+DIAGNOSTIC_UPPERBOUND-100) dPtr+=sprintf(dPtr,

/* Sets the configuration for the hDriver.  Configuration must be set before
 * hDriver is initialized.
 * pType: portType (PARALLELPORT, SERIALPORT, USBPORT)
 * portNum: Indicates which port to use
 * tickCount: delay for clocking waveforms
 * conf[]: eight character array indicating configuration:  configLoc1,
 *         triggerDelay0, triggerDelay1, triggerDelay2, triggerDelay3,
 *         sampleRate0, sampleRate1, sampleRate2
 * buffSz: buffer size per channel
 * returns: 1 if successful, 0 otherwise */
int hDriverSetConfig(int pType, int portNum, int tickCount, char conf[], int buffSz);

/* Gets the configuration from the hDriver after it is set.
 * pType: portType (PARALLELPORT, SERIALPORT, USBPORT)
 * portNum: Indicates which port to use
 * tickCount: delay for clocking waveforms
 * conf[]: eight character array indicating configuration:  configLoc1,
 *         triggerDelay0, triggerDelay1, triggerDelay2, triggerDelay3,
 *         sampleRate0, sampleRate1, sampleRate2
 * buffSz: buffer size per channel
 * returns: 1 if successful, 0 otherwise */
int hDriverGetConfig(int* pType, int* portNum, int* tickCount, char conf[], int* buffSz);

/* Initialize the hDriver by opening the ports, setting pins, etc.
 * returns: 1 if successful, 0 otherwise */
int hDriverInitialize();

/* Reports the trigger level in Volts (note the trigger is on channel 1)
 * chan: Channel to report trigger level on.  1 = Ch1.  2 = Ch2.  Any other number means use the trigger channel.
 * returns: the trigger level */
double getTriggerLevel(char chan);

/* Reports the maximum number of samples per channel
 * returns: the maximum number of samples per channel */
int getMaxSamplesPerChannel();

/* Reports the number of samples per channel
 * returns: the number of samples per channel */
int getSamplesPerChannel();

/* Sets the samples per channel
 * spchannel: samples per channel
 * returns: the cooresponding bufferSize */
int setSamplesPerChannel(int spchannel);

/* Adjusts the sample rate either fine or course up or down
 * sampleRateAdj:  ADJ_NOADJ (no adjustment), ADJ_CINCR (course increase),
 *     ADJ_FINCR (fine increase), ADJ_CDECR (course decrease),
 *     ADJ_FDECR (fine decrease)
 * returns: 1 if limits are hit.
 */
int sampleRateChange(char sampleRateAdj);

/* Adjusts the trigger delay either fine or course up or down
 * triggerDelayAdj:  ADJ_NOADJ (no adjustment), ADJ_CINCR (course increase),
 *     ADJ_FINCR (fine increase), ADJ_CDECR (course decrease),
 *     ADJ_FDECR (fine decrease)
 * returns: 0
 */
int triggerDelayChange(char triggerDelayAdj);

/* Returns the frequency of the sample rate in Hz */
double getSampleRate();

/* Sets the sample rate to the rate in sRate (Hz)
 * srate: the DESIRED sample rate in Hz
 * returns: the ACTUAL sample rate in Hz */
double setSampleRate(double sRate);

/* Returns the maximum possible sample rate of the device */
double getMaxSampleRate();

/* Returns the delay from the trigger level to beginning of capture in seconds */
double getTriggerDelay();

/* Adjust the delay associated with the trigger
 * tDelay: the DESIRED trigger delay in seconds
 * returns: the ACTUAL trigger delay in seconds */
double setTriggerDelay(double tDelay);

/* Switch to true XY capture mode based on state passed
 * state: 1 indicates true XY mode on, 0 inidcates true XY mode off
 * returns: 0 if action wasn't taken, 1 if action was taken */
int setTrueXY(char state);

/* Returns 1 if true XY mode is on otherwise returns 0. */
int getTrueXY();

/* Switch modes between using repetitive sampling or not.  Repetitive sampling
 * is sampling a waveform using multiple trigger events to construct a picture
 * of the waveform displayed as if it was sampled at a higher sampling rate
 * using one trigger event.
 * state: 1 indicates use repetitive sampling modes
 * returns: 0 if action wasn't taken, 1 if action was taken */
int setRepetitive(char state);

/* Retuns 1 if repetitive sampling is being used, 2 if repetitive sampling is
 * available but not being used, and 0 if not used at all. */
int getRepetitive();

/* Turns the trigger on or off
 * state: 1 turns trigger on, 0 turns trigger off
 * returns: 0  */
int enableTrigger(char state);

/* Indicates the status of the trigger
 * Returns 1 if trigger is enabled, otherwise returns 0  */
int getEnableTrigger();

/* Sets the trigger slope either positive of negative
 * state: 1 denotes positive slope, 0 denotes negative slope
 * returns: 0  */
int triggerSlope(char state);

/* Gets the trigger slope.
 * returns: 1 is slope is positive, 0 if slope is negative */
int getTriggerSlope();

/* Gets the trigger Channel
 * returns: 1 for channel 1, 2 for channel 2
 */
int getTriggerChannel();
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

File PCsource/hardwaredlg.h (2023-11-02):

/* ==============================================================================
 * Author:  Jonathan Weaver, jonw0224@aim.com
 * E-mail Contact: jonw0224@aim.com
 * Description:  Hardware Dialog Box.
 * Version: 2.18
 * Date: 1/17/2014
 * Filename:  hardwaredlg.c, hardwaredlg.h
 *
 * Versions History:
 *      2.01 - 4/29/2007 - Added hardware dialog
 *      2.18 - 1/17/2014 - Added COM ports 10 thru 19
 *
 * Copyright (C) 2007-2014 Jonathan Weaver
 *
 * This file is part of PPMScope.
 *
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
 * ==============================================================================
 */

#define HARDWAREDLG                 4050
#define HDWDLG_PORTTYPE             4051
#define HDWDLG_PORT                 4052
#define HDWDLG_IODELAY              4053
#define HDWDLG_PORTADDRESS          4068
#define HDWDLG_IODELAY_LABEL        4066
#define HDWDLG_VERSION              4067
#define HDWDLG_TESTEN               4054
#define HDWDLG_DATAHIGH             4055
#define HDWDLG_DATALOW              4056
#define HDWDLG_DATASTATE            4057
#define HDWDLG_DATAINHIGH           4058
#define HDWDLG_DATAINLOW            4059
#define HDWDLG_DATAINSTATE          4060
#define HDWDLG_CLOCKHIGH            4061
#define HDWDLG_CLOCKLOW             4062
#define HDWDLG_CLOCKSTATE           4063
#define HDWDLG_OK                   4064
#define HDWDLG_CANCEL               4065
#define HDWDLG_PORTADDRESS_LABEL    4069
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
